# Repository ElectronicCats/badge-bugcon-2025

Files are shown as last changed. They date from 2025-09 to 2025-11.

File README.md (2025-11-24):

# Badge BugCon 2025

El Badge BugCon 2025 es un dispositivo de hardware abierto diseñado para la comunidad de hackers, desarrolladores y entusiastas de la tecnología. Cuenta con un potente procesador Linux capaz de ejecutar aplicaciones personalizadas, junto con una amplia variedad de interfaces para ampliar su funcionalidad.

## 🚀 Características Principales

### Procesador principal 
- **RV1106**: Procesador Linux de alto rendimiento
  - ARM Cortex-A7 + MCU RISC-V
  - NPU integrada (Unidad de Procesamiento Neural)
  - ISP integrado (Procesador de Señal de Imagen)
  - Soporte completo para sistemas operativos Linux

### Interfaces y Conectividad
- **GPIOs**: Múltiples pines de propósito general
- **MIPI CSI**: Interfaz para cámaras y sensores de imagen
- **UART**: Comunicación serial asíncrona
- **SPI**: Comunicación periférica de alta velocidad
- **I2C**: Bus de comunicación para sensores y pantallas
- **USB**: Puerto USB con hub integrado
- **Ethernet**: Puerto Ethernet basado en GPIO para conectividad por cable

### Periféricos Integrados
- **Neopixels**: LEDs RGB programables WS2812E
- **Batería**: Soporte para baterías 18650 con gestión de energía
- **Buck Converter**: Regulación eficiente DC-DC
- **USB-A**: Soporte para dispositivos externos

## 📦 Componentes del Proyecto

El proyecto está dividido en dos directorios principales:

### 1. Badge Principal (`Badge_Bugcon_2025/`)
Incluye el diseño principal:
- Procesador RV1106G3
- LEDs Neopixel WS2812E
- Gestión de energía y batería
- Interfaces USB

### 2. Add-on (`Add_On_Bugcon_2025/`)
Placa de expansión que incluye:
- Microcontrolador PY32F002AA15M
- Componentes adicionales para capacidades extendidas
- Diseño decorativo personalizado

## 📋 Especificaciones Técnicas

| Componente | Especificación |
|---|---|
| Procesador | RV1106G3 (ARM Cortex-A7 + RISC-V MCU + NPU + ISP) |
| Sistema Operativo | Linux |
| LEDs | WS2812E Neopixels |
| Batería | Soporte 18650 |
| Interfaces | USB, Ethernet, UART, SPI, I2C, MIPI CSI, GPIOs |

## 🔌 Interfaces del RV1106

El procesador RV1106 ofrece las siguientes interfaces:

### Comunicación
- **UART**: Comunicación serial (debug/terminal)
- **SPI**: Interfaz periférica de alta velocidad
- **I2C**: Para sensores, pantallas y otros dispositivos I2C
- **USB**: Hub USB integrado

### Red
- **Ethernet**: Conectividad por cable mediante una interfaz basada en GPIO
- **WiFi (NO INCLUIDO)**: Conectividad por USB mediante el USB HUB, drivers disponibles ya instalados en kernel.

### Multimedia e Imagen
- **MIPI CSI**: Interfaz para cámaras y sensores de imagen
- **ISP**: Procesador de señal de imagen integrado

### Control
- **GPIOs**: Pines de propósito general
- **PWM**: Canales PWM para control de LEDs y motores

# Primeros pasos 

El badge Bugcon 2025 está basado en el hardware y el SDK del Luckfox Pico Pro Max. Para información general, consulta la Wiki oficial de Luckfox. El badge incorpora el RV1106G3, un microprocesador de bajo consumo de Rockchip, basado en una CPU ARM y un co-procesador RISC-V de 32 bits optimizada para aplicaciones de codificación y decodificación de audio y video.

Nuestro primer badge con Linux embebido!

El badge es compatible con múltiples interfaces, incluyendo GPIO, UART, SPI, I²C, USB, entre otras, lo que facilita un desarrollo rápido y una depuración eficiente.

## 🔌 Conectarse al puerto serial (Debug Serial)

Para interactuar con el badge (ejecutar comandos, ver logs o depurar), debes conectarte al puerto DEBUG SERIAL mostrado en la imagen anterior.
Este puerto corresponde a la UART2 del RV1106:

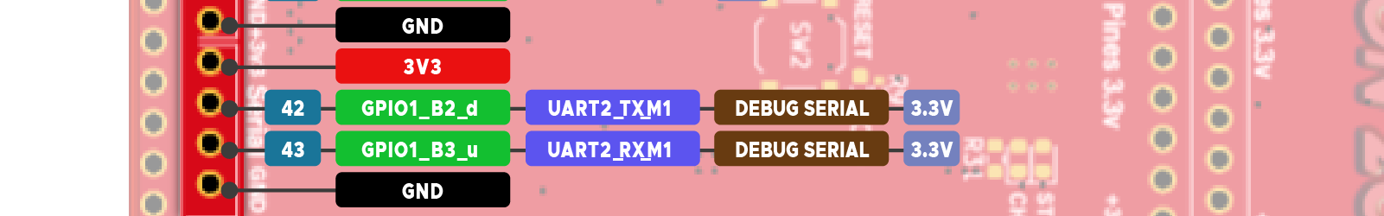
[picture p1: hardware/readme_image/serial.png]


```
TX → GPIO1_B2_d
RX → GPIO1_B3_u
```
⚠ Importante: La señal del puerto serial del badge es 3.3V TTL.

## ✔ Adaptadores USB–Serial compatibles

Puedes usar cualquier adaptador USB a UART de 3.3V, por ejemplo:

CH340 / CH341
CP2102 / CP2104
FT232RL
PL2303
CP2105

Matek F405 adapters (soportan 3.3V)

Asegúrate de:
```
TX del adaptador → RX del badge
RX del adaptador → TX del badge
GND → GND
```

## 💻 Cómo abrir la terminal serial

A continuación, cómo conectarte desde Linux, macOS y Windows.

## 🐧 Linux

Conecta el adaptador USB-serial.

Verifica qué puerto creó:
```
dmesg | grep tty
```

Normalmente aparecerá como:
```
/dev/ttyUSB0
/dev/ttyACM0
```
Conéctate con screen o minicom:

Con screen (lo más fácil)
```
screen /dev/ttyUSB0 115200
```

Para salir:
CTRL + A luego K (y confirma).

Con minicom
```
sudo minicom -b 115200 -D /dev/ttyUSB0
```

## 🍎 macOS

Conecta el adaptador USB-UART.

Ver puertos disponibles:
```
ls /dev/tty.*
```

Suelen ser:
```
/dev/tty.usbserial-*
/dev/tty.wchusbserial*
/dev/tty.SLAB_USBtoUART
```

Conéctate:

```
screen /dev/tty.usbserial-XXXX 115200
```

Para salir:
CTRL + A, luego K.

Mac también permite usar CoolTerm (GUI amigable).

## 🪟 Windows

Usa un cliente serial como:
```
PuTTY
TeraTerm
CoolTerm
RealTerm
```

Conecta el adaptador USB-UART.

Abre el Administrador de dispositivos → “Puertos (COM y LPT)”

Identifica el puerto COM, ejemplo: COM4

Abre PuTTY o TeraTerm y selecciona:
```
Port: COM4
Baudrate: 115200
Data bits: 8
Parity: None
Stop bits: 1
Flow control: None
```
Con eso verás la consola del badge.

## Pinout 

Los números de pines correspondientes a los GPIO se encuentran marcados en el diagrama de pinout. Puedes utilizarlos para configurar un pin como GPIO.
Para más información, consulta la wiki de GPIO de Luckfox.e.

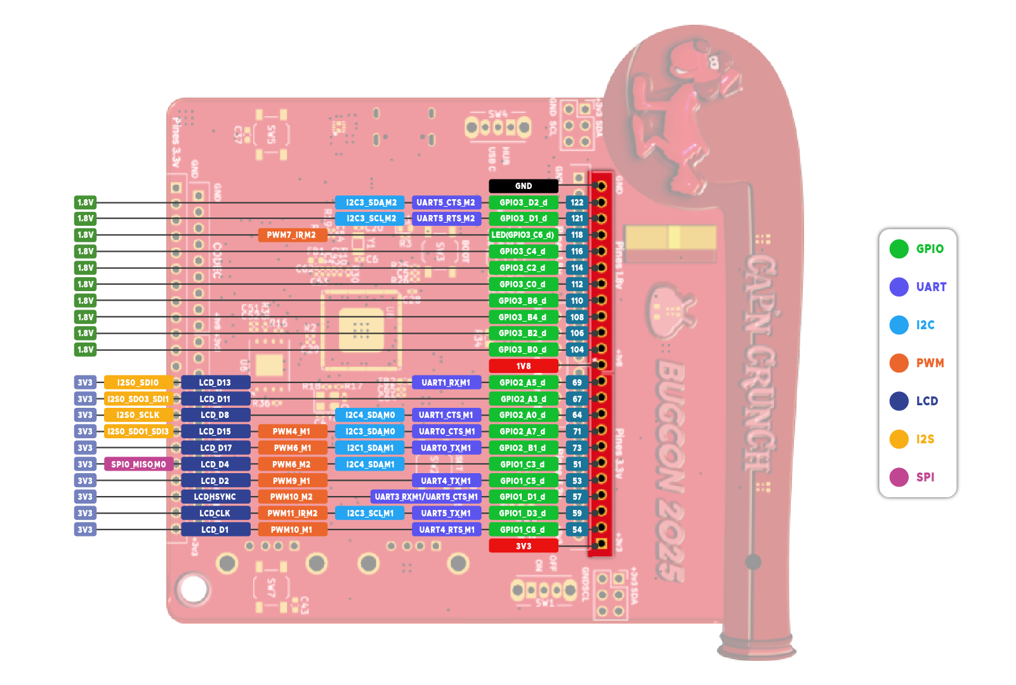
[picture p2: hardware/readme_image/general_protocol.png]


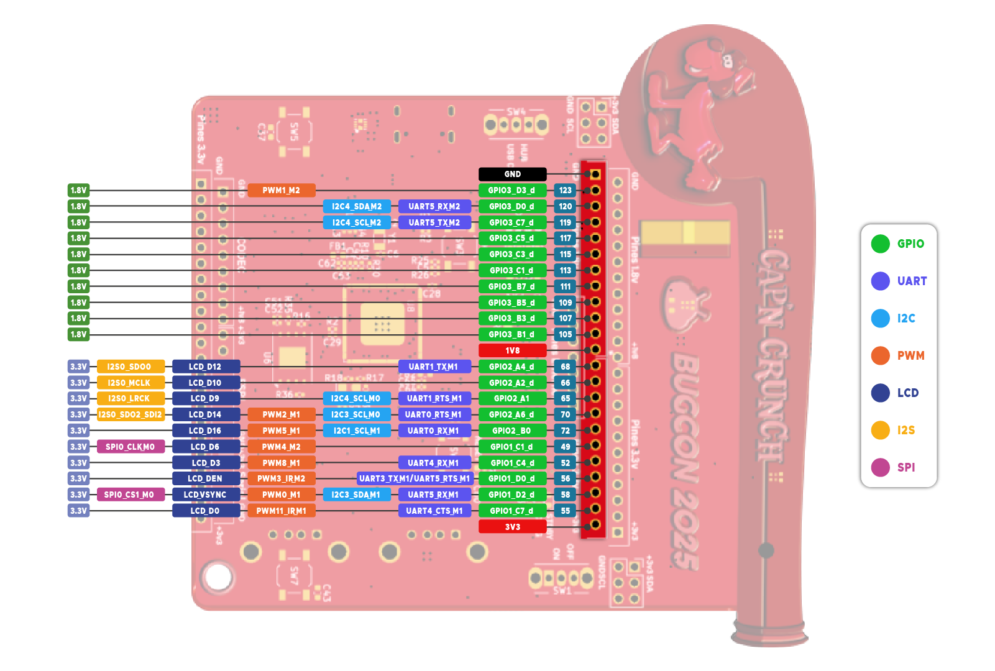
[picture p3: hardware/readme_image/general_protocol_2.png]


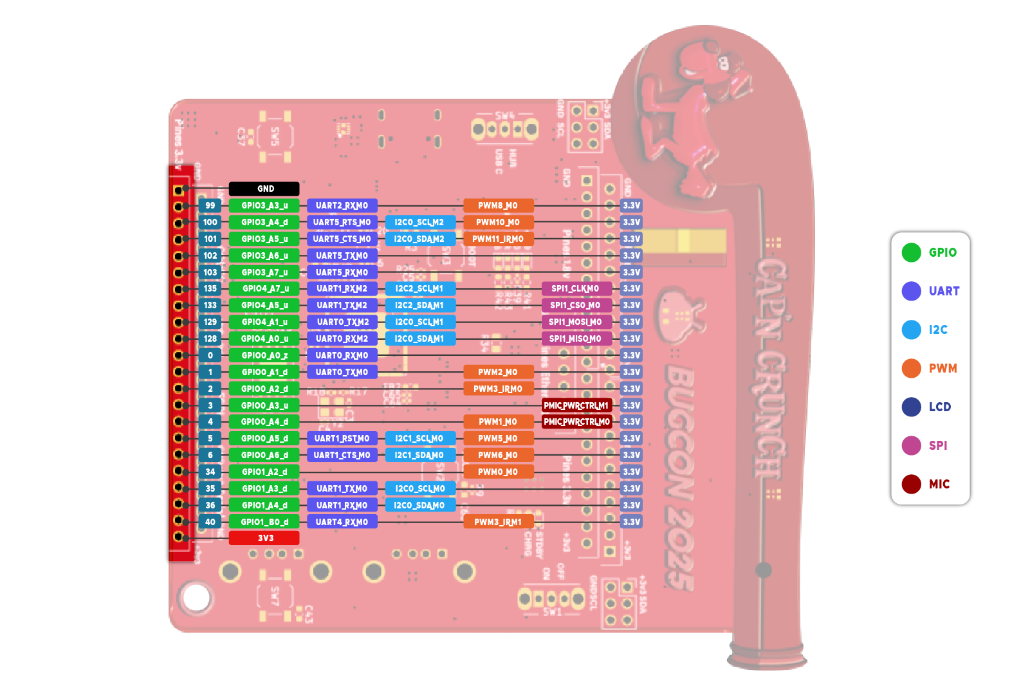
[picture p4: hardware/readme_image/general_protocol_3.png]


Los números de pines correspondientes a los GPIO se encuentran marcados en el diagrama de pinout. Puedes utilizarlos para configurar un pin como GPIO.
Para más información, consulta la wiki de GPIO de Luckfox.

- [GPIO](https://wiki.luckfox.com/Luckfox-Pico-Pro-Max/GPIO)

La tarjeta también es compatible con Ethernet de 10/100 Mbps. Ten en cuenta que es necesario agregar el transformador Ethernet (Ethernet transformer) y el common-mode choke para garantizar el funcionamiento adecuado del dispositivo.

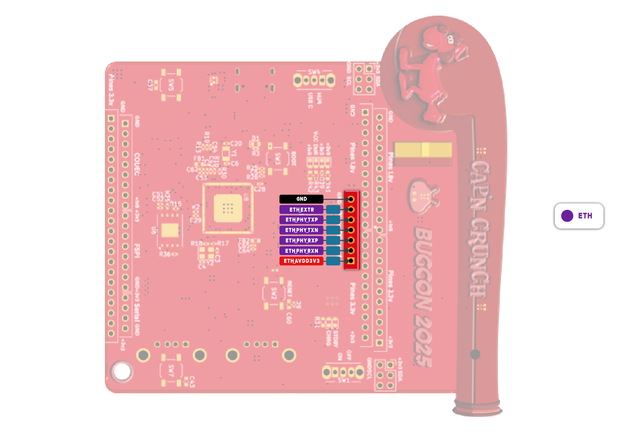
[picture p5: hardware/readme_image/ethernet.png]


Finalmente, la tarjeta permite conectar micrófonos analógicos externos a través de la entrada del códec. El CPU también puede generar señales de audio digital PCM (Pulse-Code Modulation), las cuales pueden convertirse en señales analógicas para reproducción.
Es importante destacar que la señal analógica utilizada para reproducción requiere su propio amplificador para evitar problemas relacionados con la corriente.

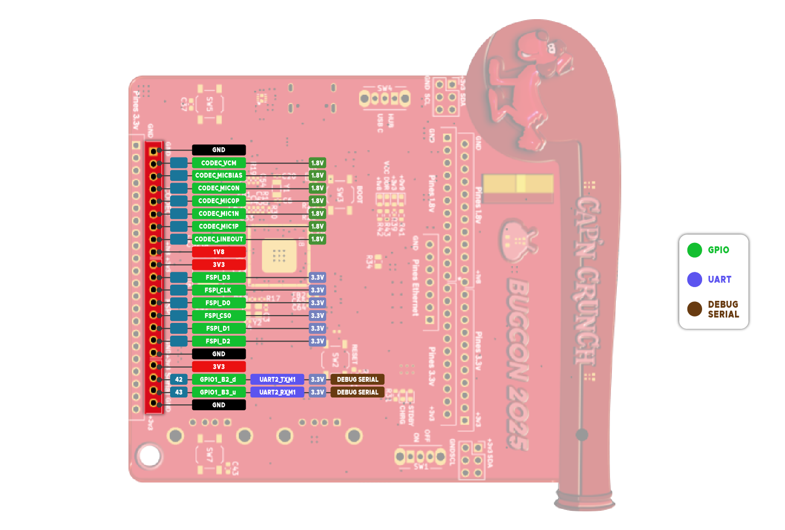
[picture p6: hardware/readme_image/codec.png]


Para más información, consulta la wiki de audio de Luckfox:

- [Audio](https://wiki.luckfox.com/Luckfox-Pico-Ultra/Audio)

IMPORTANTE: No utilices los pines FSPI. Estos están conectados directamente a la memoria flash. Cualquier alteración en sus señales puede provocar fallos en el funcionamiento del badge.

## Blink Blink!
Presiona los botones que se encuentran al frente del badge y enciende los leds!!

## Acceso:

Para acceder al dispositivo los accesos son:

*usuario:* root

*password:* 1337

## Hola Mundo

El badge ya incluye Python 3.11.6, por lo que puedes ejecutar scripts de Python directamente desde la terminal sin necesidad de configurar nada adicional.

Esta breve guía muestra cómo crear y ejecutar un simple programa “Hola Mundo”.

1. En la terminal, crea un nuevo archivo:

```
nano nombre.py
```
o
```
vi nombre.py
```

Agrega esta linea:
```
print("Hola mundo!")
```
2. Ejecuta el archivo

```
python3 nombre.py
```

you should see
```
Hola mundo !
``` 

## NEOPIXELES

Los LEDs RGB WS2812B y WS2812E-1313 pueden controlarse utilizando el módulo de Python spidev a través de la interfaz SPI del RV1106.
Es importante destacar que SPI se utiliza como un generador de trenes de pulsos a 800 kHz, lo cual es necesario para el funcionamiento correcto de los NeoPixel.

Una vez habilitados los módulos en la interfaz de configuración y grabada la tarjeta, el siguiente paso será crear un script de Python en el entorno de Buildroot dentro de la PCB.
```
nano /root/[nombre del scrip].py
```
Puede ser algo como esto:

```
#!/usr/bin/env python3
import spidev, time, threading

SPI_SPEED_HZ = 2400000
NUM_LEDS = 8

def byte_to_spi(byte):
    spi_bytes = []
    for i in range(8):
        if byte & (1 << (7-i)):
            spi_bytes.append(0b1110)  # '1'
        else:
            spi_bytes.append(0b1000)  # '0'
    return spi_bytes

def color_to_spi(r, g, b):
    data = []
    data += byte_to_spi(g)
    data += byte_to_spi(r)
    data += byte_to_spi(b)
    return data

def make_buffer(r, g, b):
    buf = []
    for _ in range(NUM_LEDS):
        buf += color_to_spi(r, g, b)
    return buf

def run_spi(bus, device, colors):
    spi = spidev.SpiDev()
    spi.open(bus, device)
    spi.max_speed_hz = SPI_SPEED_HZ

    try:
        while True:
            for (r,g,b) in colors:
                buffer = make_buffer(r,g,b)
                spi.xfer2(buffer)
                time.sleep(1)
    except KeyboardInterrupt:
        spi.xfer2(make_buffer(0,0,0))
        spi.close()

def main():
    colors = [(255,0,255), (0,255,0), (0,0,255)]  # rosa, verde, azul

    t0 = threading.Thread(target=run_spi, args=(0,0,colors))
    #t1 = threading.Thread(target=run_spi, args=(1,0,colors))

    t0.start()
    #t1.start()

    t0.join()
    #t1.join()

if __name__ == "__main__":
    main()

```
El script controla tanto los LEDs WS2812B como WS2812B-1313 a través de spi0 y spi1, alternando entre cuatro colores diferentes (azul, rojo, verde y rosa) cada segundo.
Una vez creado, ejecuta el script:
```
python3 /root/[nombre del scrip].py
```

## Device tree source 

El Device Tree es utilizado en el kernel de Linux para describir el hardware de una placa.
Está compuesto por archivos de texto con extensiones .dts (Device Tree Source) y .dtsi (Device Tree Source Include).
El archivo .dts define el hardware específico de la placa, mientras que el archivo .dtsi contiene configuraciones comunes o compartidas por múltiples .dts.

Puedes utilizar el Device Tree para habilitar, deshabilitar y/o configurar los diferentes periféricos que la tarjeta ofrece.
Los archivos del Device Tree se encuentran en el siguiente directorio del SDK:

```
 luckfox-pico SDK/sysdrv/source/kernel/arch/arm/boot/dts
```
Para más información, consulta la wiki de DTS de Luckfox:

- [DTS](https://wiki.luckfox.com/Luckfox-Pico-Ultra/Device-Tree)

## USB host mode 

Puede modificar la configuración del device tree para establecerlo como un USB HOST, lo que le permitirá ampliar múltiples interfaces mediante un USB HUB.

1. Abre la herramienta de luckfox-config en la terminal de la badge:

```
luckfox-config
```

2. Selecciona "Advanced Options":

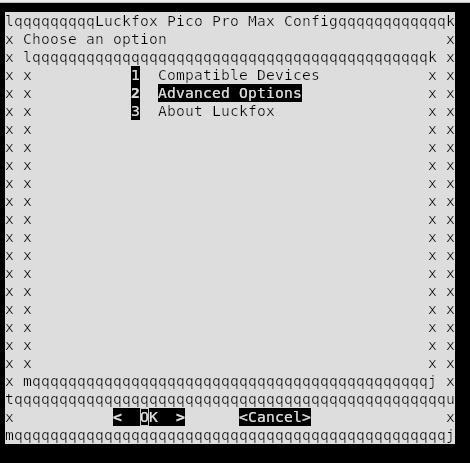
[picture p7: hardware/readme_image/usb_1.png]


3. Selecciona "USB" :

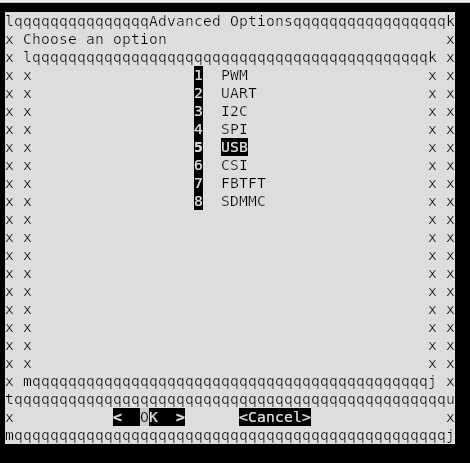
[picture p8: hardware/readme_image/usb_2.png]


4. Selecciona el modo "HOST": 

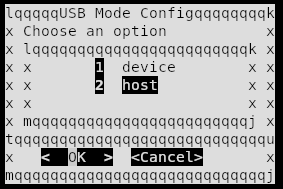
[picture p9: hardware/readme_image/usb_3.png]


5. Una vez seleccionado, usar la tecla "Esc" para salir.

# Cargar la imagen 

## Windows

Para cargar la imagen a traves de windows, es necesario descargar este zip:
```
https://drive.google.com/drive/folders/1J3xfAAmFQHFgw1gC7Ql5-bSOi6YOyE-3
```

La carpeta contiene varias imagenes necesarias para el flasheo de la placa Bugcon2025.
Una vez descargada, por favor seguir las intrucciones de la wiki de luckfox:
```
https://wiki.luckfox.com/Luckfox-Pico-Pro-Max/Flash-image
```

## Linux

1. [Descargar](https://wiki.luckfox.com/assets/files/upgrade_tool_v2.17-bfd48dcdba9fd8013872ca2abff19a8d.zip) y extraer la herramiente de actualizacion de Rockchip.
   
3. Del release, descargar y descomprimir el archivo comprimido Bugcon-Badge-2025-vX.X.tar.xz. 
    
4. Mantenga presionado el botón BOOT mientras conecta la placa a la computadora anfitriona para entrar en modo de flasheo.

5. Una vez que tengas la placa en modo BOOT, procede a flashearla. Para ello, tendras que usar el .img que se encuentra en el archivo previamente descomprimido (modifique la ruta según la ubicación real de la imagen):

```
sudo ./upgrade_tool uf  {PATH-TO-IMAGE}/Bugcon-Badge-2025-v1.0.img
```

## MAC OS

1. [Descargar](https://wiki.luckfox.com/files/RV1106/upgrade_tool_v2.44_for_mac.zip) y extraer la herramienta de actualizacion

2. Del release, descargar y descomprimir el archivo comprimido Bugcon-Badge-2025-v1.0.tar.xz. 
    
3. Mantenga presionado el botón BOOT mientras conecta la placa a la computadora anfitriona para entrar en modo de flasheo.

4. Una vez que tengas la placa en modo BOOT, procede a flashearla. Para ello, ejecute el programa para flashear el firmware (modifique la ruta según la ubicación real de la imagen) y use el .img previamente descomprimido:
```
sudo ./upgrade_tool uf  {PATH-TO-IMAGE}/Bugcon-Badge-2025-v1.0.img
```

## 📖 Documentación Adicional

- [KiCad Documentation](https://docs.kicad.org/)
- [RV1106 Datasheet](https://files.luckfox.com/wiki/Luckfox-Pico/PDF/Rockchip%20RV1106%20Datasheet%20V1.7-20231218.pdf)
- [Proyecto basado en Luckfox](https://wiki.luckfox.com/Luckfox-Pico-RV1106)
- [SDK basado en Badge](https://github.com/ElectronicCats/luckfox-pico/tree/bugcon2025)

## 🤝 Contribuciones

Este es un proyecto de hardware abierto. Las contribuciones son bienvenidas:

1. Haz un fork del repositorio.
2. Crea una nueva rama para tu feature (`git checkout -b feature/AmazingFeature`)
3. Haz commit de tus cambios (`git commit -m 'Add some AmazingFeature'`)
4. Haz push a tu rama (`git push origin feature/AmazingFeature`)
5. Abre un Pull Request

## 📝 Licencia

Este proyecto es de hardware abierto. Consulta los archivos de licencia para más detalles.

## 🏢 Electronic Cats

Desarollado con ❤️ por [Electronic Cats](https://www.electroniccats.com/)

<a href="https://github.com/sponsors/ElectronicCats">

</a>

Electronic Cats invierte tiempo y recursos en proporcionar este diseño de hardware abierto.
Por favor, apoya a Electronic Cats y al hardware abierto comprando productos de Electronic Cats.

## 📞 Contacto y soporte 

- **Website**: [https://www.electroniccats.com/](https://www.electroniccats.com/)
- **GitHub**: [ElectronicCats](https://github.com/ElectronicCats)
- **Issues**: Usa la sección de Issues en GitHub para reportar problemas o sugerir mejoras

## 🙏 Agradecimientos

Gracias a toda la comunidad de hardware abierto y a todas las personas que hacen posibles proyectos como este.
---

Nota: Este badge está diseñado para BugCon 2025. Para más información sobre el evento, visita la página oficial de BugCon.

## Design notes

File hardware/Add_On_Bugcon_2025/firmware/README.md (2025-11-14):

# PY32F0 Template Project for Windows

More about hardware and development kit:  [TDLOGY Dev Resource](https://github.com/TDLOGY/PY32F002A-Dev-Resource)

Fork from: https://github.com/IOsetting/py32f0-template with modify makefile to support Windows

* Puya PY32F0 seriees template project for GNU Arm Embedded Toolchain
* Supported programmers: J-Link
* Supported IDE: VSCode

# Puya PY32F0 Family

* PY32F002A
  * PY32F002Ax5(20KB Flash/3KB RAM)

**Note**

There is high probability that PY32F002A, PY32F003 and PY32F030 share the same core, you can treat them all as PY32F030 in coding and programming.

# File Structure

```
├── Build                       # Build results
├── Docs                        # Datesheets and User Manuals
├── Examples
│   ├── FreeRTOS                # FreeRTOS examples
│   ├── HAL                     # HAL library examples
│   └── LL                      # LL(Low Layer) library examples
├── Libraries
│   ├── BSP                     # SysTick delay and printf for debug
│   ├── BSP_LL                  # SysTick delay and printf for debug
│   ├── CMSIS
│   ├── FreeRTOS                # FreeRTOS library
│   ├── LDScripts               # LD files
│   ├── PY32F0xx_HAL_Driver     # MCU peripheral driver
│   └── PY32F0xx_LL_Driver      # MCU low layer peripheral driver
├── Makefile                    # Make config
├── Misc
│   ├── Flash
│   │   ├── JLinkDevices        # JLink flash loaders
│   │   └── Sources             # Flash algorithm source code
│   ├── Puya.PY32F0xx_DFP.x.pack # DFP pack file for PyOCD
│   └── SVD                     # SVD files
├── README.md
├── rules.mk                    # Pre-defined rules include in Makefile 
└── User                        # User application code
```

# Requirements

* PY32F0 EVB or boards of PY32F002/003/030 series: https://linhkienthuduc.com//product/search?search=PY32
* Programmer
  * J-Link: J-Link OB programmer: https://linhkienthuduc.com/jlink-ob-072-mach-nap-cho-arm-cortex-m
* SEGGER J-Link Software and Documentation pack [https://www.segger.com/downloads/jlink/](https://www.segger.com/downloads/jlink/)
* GNU Arm Embedded Toolchain
* Make 

# Building

## 1a. Install GNU Arm Embedded Toolchain

Download the toolchain from [Arm GNU Toolchain Downloads](https://developer.arm.com/downloads/-/arm-gnu-toolchain-downloads) according to your pc architecture, extract the files and install:

**Note: Don't download Cortex-M PACBTI Version**

## 1b. Install Make
Download make 3.81 Binaries from: https://gnuwin32.sourceforge.net/packages/make.htm

**Note: Add Make path to PATH: C:\Program Files (x86)\GnuWin32\bin**

## 2. : Install SEGGER J-Link (Must)

Download and install JLink from [J-Link / J-Trace Downloads](https://www.segger.com/downloads/jlink/).

Must: Copy [Project directory]/Misc/Flash/JLinkDevices to C:\Users\[Users]\AppData\Roaming\SEGGER\JLinkDevices\

Read more: [https://wiki.segger.com/J-Link_Device_Support_Kit](https://wiki.segger.com/J-Link_Device_Support_Kit)

## 3. Clone This Repository

Clone this repository to local workspace
```
git clone https://github.com/TDLOGY/py32f0-template-project
```

Or download directly from link: https://github.com/TDLOGY/py32f0-template-project

## 4. Edit Makefile

Change the settings in Makefile
* **USE_LL_LIB** Puya provides two sets of library, HAL and LL, set `USE_LL_LIB ?= y` to use LL instead of HAL.
* **ENABLE_PRINTF_FLOAT** set it to `y` to `-u _printf_float` to link options. This will increase the binary size.
* **USE_FREERTOS** Set `USE_FREERTOS ?= y` will include FreeRTOS in compilation
* **USE_DSP** Include CMSIS DSP or not
* **FLASH_PROGRM**
  * If you use J-Link, `FLASH_PROGRM` jlink
  * ST-LINK is not supported yet.
* **ARM_TOOCHAIN** Make sure it points to the correct path of arm-none-eabi-gcc

```makefile
##### Project #####

PROJECT           ?= app
# The path for generated files
BUILD_DIR         = Build

##### Options #####

# Use LL library instead of HAL, y:yes, n:no
USE_LL_LIB        ?= n
# Enable printf float %f support, y:yes, n:no
ENABLE_PRINTF_FLOAT ?= n
# Build with FreeRTOS, y:yes, n:no
USE_FREERTOS      ?= n
# Build with CMSIS DSP functions, y:yes, n:no
USE_DSP           ?= n
# Programmer, jlink or pyocd
FLASH_PROGRM      ?= pyocd

ifeq ($(detected_OS),WIN)     # is Windows_NT on XP, 2000, 7, Vista, 10...
ARM_TOOCHAIN	?= C:/Program Files (x86)/Arm GNU Toolchain arm-none-eabi/12.2 rel1/bin
JLINKEXE		?= C:/Program Files/SEGGER/JLink/JLink
else
ARM_TOOCHAIN	?= /opt/gcc-arm/arm-gnu-toolchain-12.2.rel1-x86_64-arm-none-eabi/bin
JLINKEXE		?= /opt/SEGGER/JLink/JLinkExe
endif

# JLink device type, options:
#   PY32F002AX5, PY32F002X5, 
#   PY32F003X4, PY32F003X6, PY32F003X8, 
#   PY32F030X4, PY32F030X6, PY32F030X7, PY32F030X8
JLINK_DEVICE      ?= PY32F030X6
# path to PyOCD, 
PYOCD_EXE         ?= pyocd
# PyOCD device type, options: 
#     py32f002ax5, py32f002x5, 
#   py32f003x4,  py32f003x6, py32f003x8, 
#   py32f030x3,  py32f030x4, py32f030x6, py32f030x7, py32f030x8
#   py32f072xb
PYOCD_DEVICE      ?= py32f030x8

##### Paths ############

# Link descript file: py32f002x5.ld, py32f003x6.ld, py32f003x8.ld, py32f030x6.ld, py32f030x8.ld
LDSCRIPT          = Libraries/LDScripts/py32f002x5.ld
# Library build flags: 
#   PY32F002x5, PY32F002Ax5, 
#   PY32F003x4, PY32F003x6, PY32F003x8, 
#   PY32F030x3, PY32F030x4, PY32F030x6, PY32F030x7, PY32F030x8, 
#   PY32F072xB
LIB_FLAGS         = PY32F030x6
```

## 5. Compiling And Flashing

```bash
# clean source code
make clean
# build
make
# or make with verbose output, Linux only
V=1 make
# flash
make flash
# erase
make erase
```
# Hardware connection

Hardware connection digram

Signal Name | Kit | Jlink
--- | --- | --- | 
VCC | 5V | VCC 3.3V
GND | GND | GND
SWCLK | SCK | SWCLK
SWDIO | SWD | SWDIO
RESET | nRST | RST
MCU_UART_TX | PA2 | RXD
MCU_UART_RX | PA1 | TXD

# Debugging In VSCode

Install Cortex Debug extension, add a new configuration in launch.json, e.g.
```
{
    // Use IntelliSense to learn about possible attributes.
    // Hover to view descriptions of existing attributes.
    // For more information, visit: https://go.microsoft.com/fwlink/?linkid=830387
    "version": "0.2.0",
    "configurations": [
        {
            "cwd": "${workspaceRoot}",
            "executable": "${workspaceFolder}/Build/app.elf",
            "name": "Debug Microcontroller",
            "request": "launch",
            "type": "cortex-debug",
            "servertype": "jlink",
            "serverpath": "C:/Program Files/SEGGER/JLink/JLinkGDBServerCL.exe",
            "armToolchainPath": "C:/Program Files (x86)/Arm GNU Toolchain arm-none-eabi/12.2 rel1/bin",
            "device": "PY32F030X8",
            "interface": "swd",
            "serialNumber": "", // add J-Link serial number if having multiple attached the same time.
            "svdFile": "${workspaceFolder}/Misc/SVD/py32f030xx.svd",

            "showDevDebugOutput": "vscode", // parsed, raw, vscode:vscode log and raw
            "runToEntryPoint": "main", // "main" or other function name. runToMain is deprecated
            "preLaunchTask": "build",  // Set this to run a task from tasks.json before starting a debug session
        }
    ]
}
```

task.json
```
{
    // See https://go.microsoft.com/fwlink/?LinkId=733558
    // for the documentation about the tasks.json format
    "version": "2.0.0",
    "tasks": [
        {
            "label": "build",
            "type": "shell",
            "command": "make -j4"
        }
    ]
}
```

# Try Other Examples

More examples can be found in *Examples* folder, copy and replace the files under *User* folder to try different examples.

# Links

* Puya Product Page(Datasheet & SDK download): https://www.puyasemi.com/cpzx3/info_267_aid_242_kid_235.html

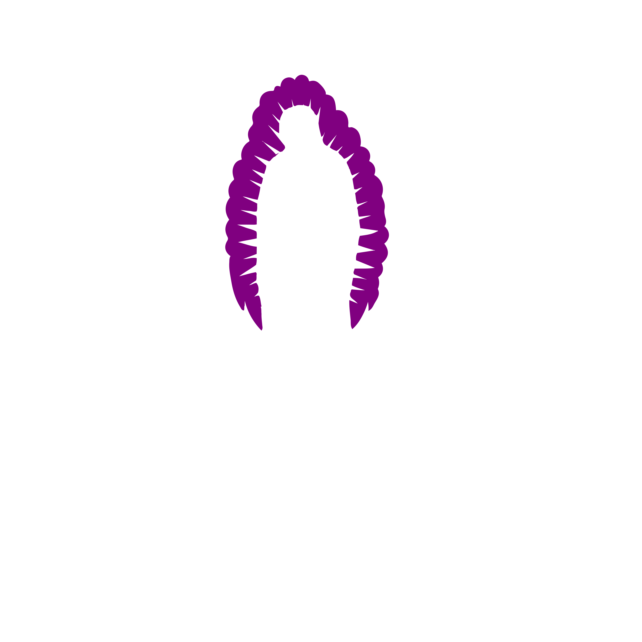
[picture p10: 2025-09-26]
hardware/Add_On_Bugcon_2025/.svg2shenzhen-cache/images/F.Cu_g587.png

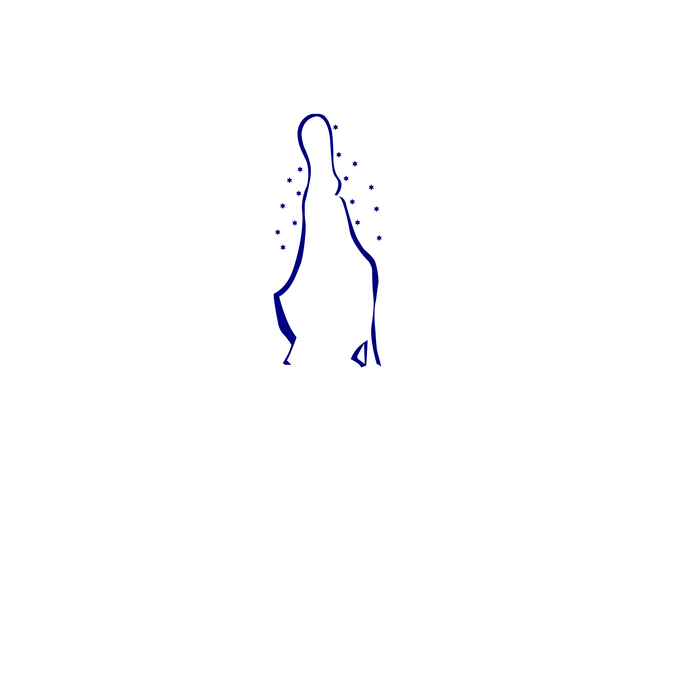
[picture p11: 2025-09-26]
hardware/Add_On_Bugcon_2025/.svg2shenzhen-cache/images/F.Mask_g589.png

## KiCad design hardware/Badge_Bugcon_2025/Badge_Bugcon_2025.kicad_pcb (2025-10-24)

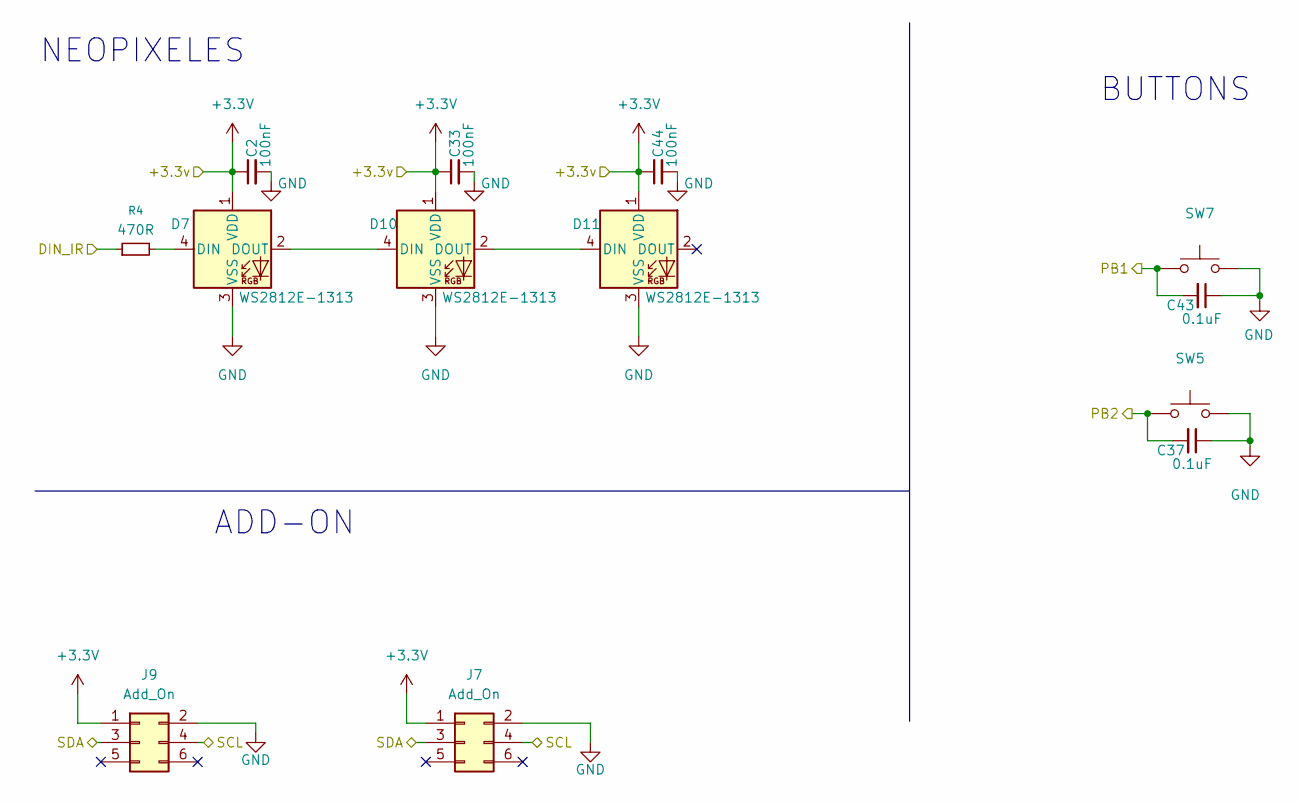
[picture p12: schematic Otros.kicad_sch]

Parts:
C2, C33, C44: 100nF; C_0402_1005Metric; LCSC# C77020
C37, C43: 0.1uF; C_0603_1608Metric; LCSC# C478888
D7, D10, D11: WS2812E-1313; LCSC# C5446700
J7, J9: Add_On; PinSocket_2x03_P2.54mm_Vertical; LCSC# C5116527
R4: 470R; R_0603_1608Metric; LCSC# C23179
SW5, SW7: SW_SPST_TL3342; LCSC# C318889

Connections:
+3.3V: C2.1, C33.1, C44.1, D7.1 (VDD), D10.1 (VDD), D11.1 (VDD), J7.1, J9.1; also elsewhere on the board
/MCU/DIN_IR: R4.1; also elsewhere on the board
/MCU/PB1: C43.2, SW7.2; also elsewhere on the board
/MCU/PB2: C37.2, SW5.2; also elsewhere on the board
/MCU/SCL: J7.4, J9.4; also elsewhere on the board
/MCU/SDA: J7.3, J9.3; also elsewhere on the board
GND: C2.2, C33.2, C37.1, C43.1, C44.2, D7.3 (VSS), D10.3 (VSS), D11.3 (VSS), J7.2, J9.2, SW5.1, SW7.1; also elsewhere on the board
unnamed: D7.4 (DIN), R4.2
unnamed: D7.2 (DOUT), D10.4 (DIN)
unnamed: D10.2 (DOUT), D11.4 (DIN)

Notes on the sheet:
BUTTONS
NEOPIXELES
ADD-ON

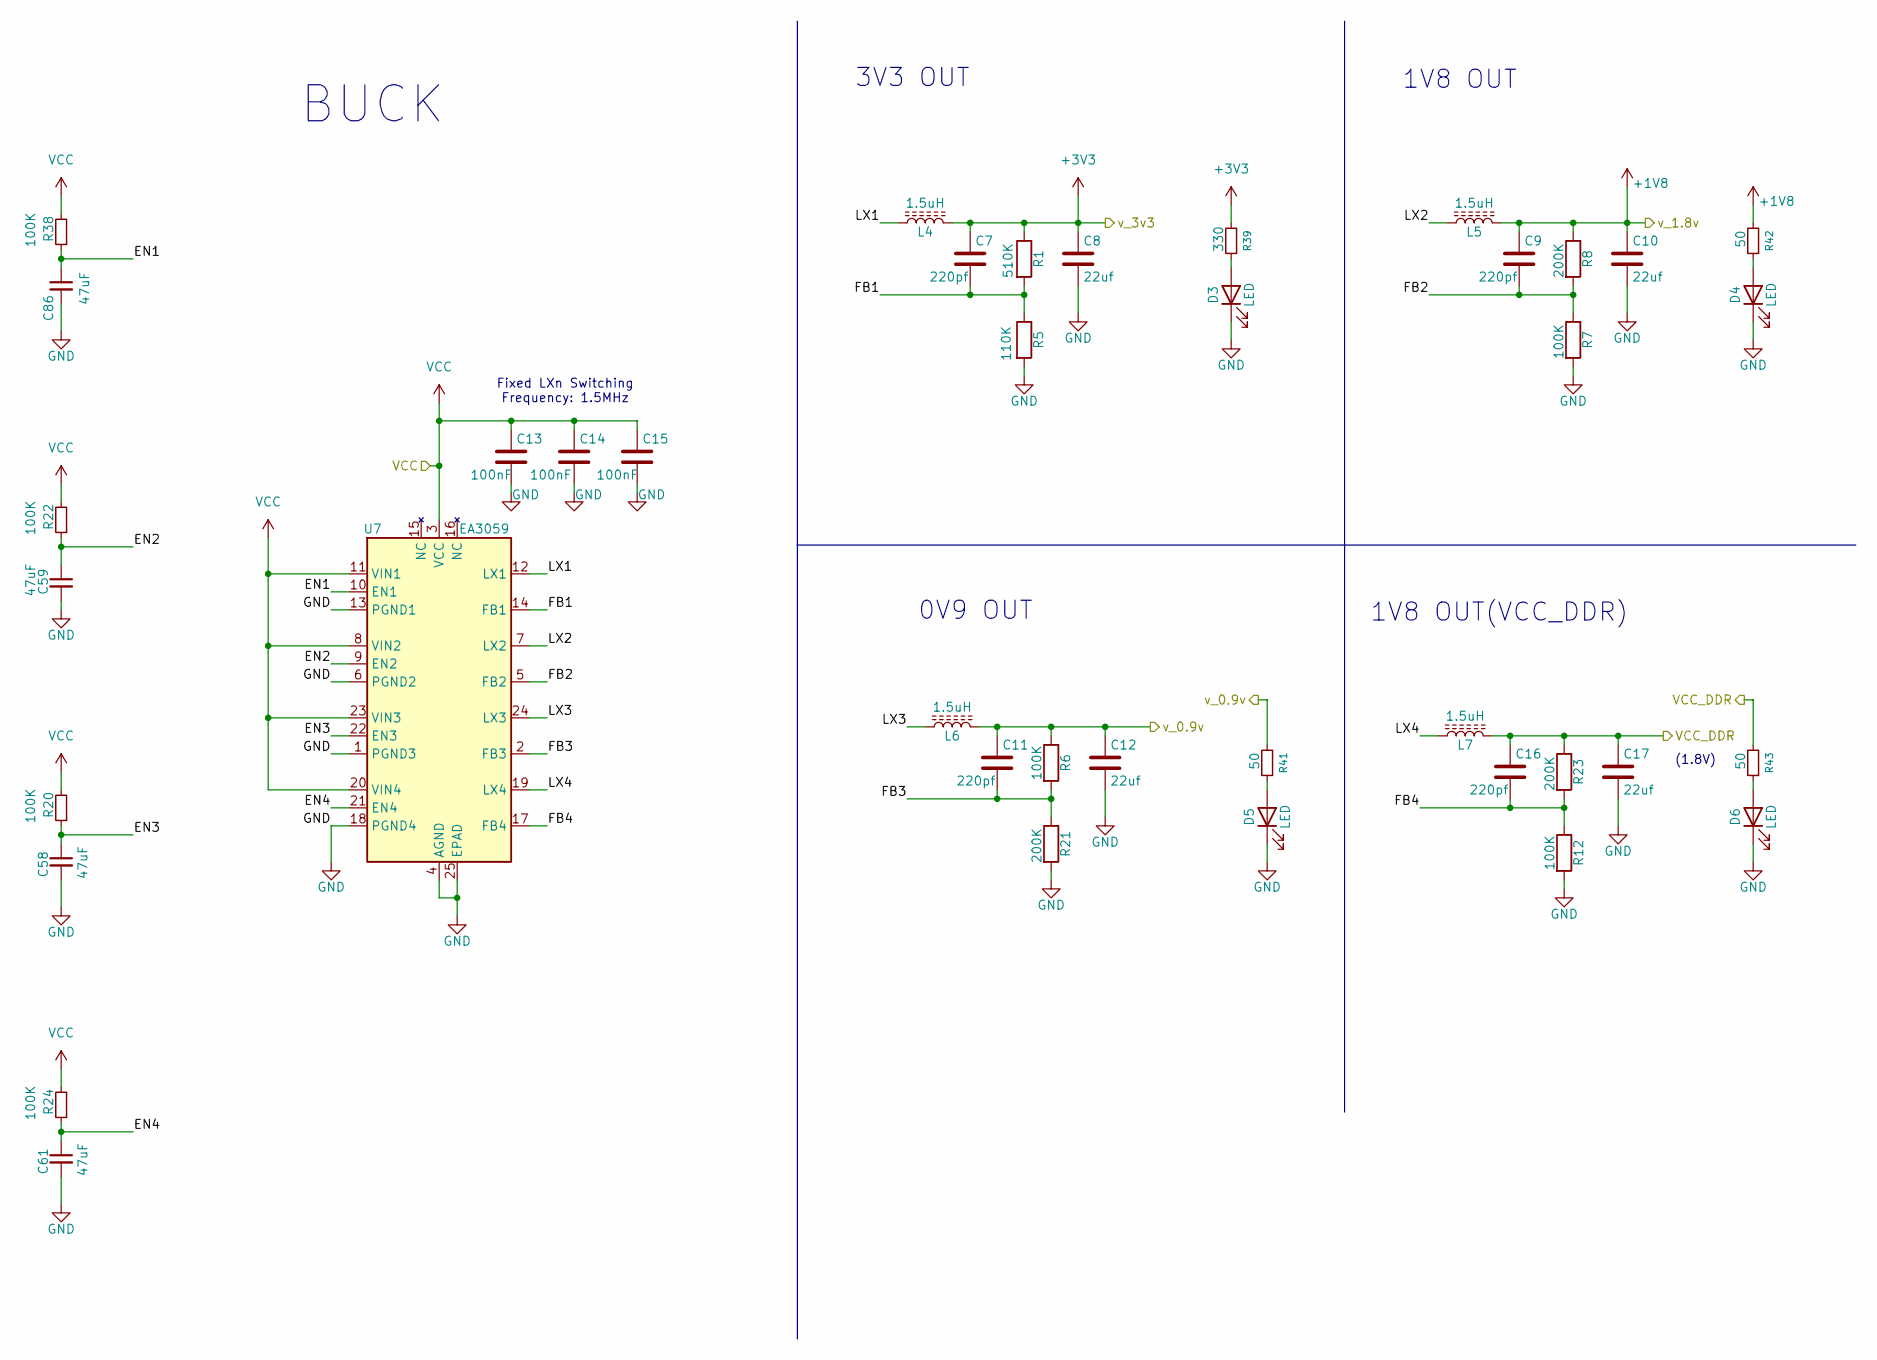
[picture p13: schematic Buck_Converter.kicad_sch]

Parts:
C7, C9, C11, C16: 220pf; C_0402_1005Metric; LCSC# C107001
C8, C10, C12, C17: 22uf; C_0402_1005Metric; LCSC# C415703
C13, C14, C15: 100nF; C_0402_1005Metric; LCSC# C77020
C58, C59, C61, C86: 47uF; C_0603_1608Metric; LCSC# C140782
D3, D4, D5, D6: LED; LED_0603_1608Metric; LCSC# C375573
L4, L5, L6, L7: 1.5uH; L_1008_2520Metric; LCSC# C7427193
R1: 510K; R_0402_1005Metric; LCSC# C365024
R5: 110K; R_0402_1005Metric; LCSC# C2909311
R6, R7, R12, R20, R22, R24, R38: 100K; R_0402_1005Metric; LCSC# C844674
R8, R21, R23: 200K; R_0402_1005Metric; LCSC# C364966
R39: 330; R_0402_1005Metric; LCSC# C105875
R41, R42, R43: 50; R_0603_1608Metric; LCSC# C2907181
U7: EA3059; VQFN-24-1EP_4x4mm_P0.5mm_EP2.5x2.5mm; LCSC# C111586

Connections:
+1V8: C9.1, C10.1, L5.2, R8.1, R42.2; also elsewhere on the board
+3V3: C7.1, C8.1, L4.2, R1.1, R39.2; also elsewhere on the board
/Buck_Converter/EN1: C86.1, R38.1, U7.10 (EN1)
/Buck_Converter/EN2: C59.1, R22.1, U7.9 (EN2)
/Buck_Converter/EN3: C58.1, R20.1, U7.22 (EN3)
/Buck_Converter/EN4: C61.1, R24.1, U7.21 (EN4)
/Buck_Converter/FB1: C7.2, R1.2, R5.1, U7.14 (FB1)
/Buck_Converter/FB2: C9.2, R7.1, R8.2, U7.5 (FB2)
/Buck_Converter/FB3: C11.2, R6.2, R21.1, U7.2 (FB3)
/Buck_Converter/FB4: C16.2, R12.1, R23.2, U7.17 (FB4)
/Buck_Converter/LX1: L4.1, U7.12 (LX1)
/Buck_Converter/LX2: L5.1, U7.7 (LX2)
/Buck_Converter/LX3: L6.1, U7.24 (LX3)
/Buck_Converter/LX4: L7.1, U7.19 (LX4)
/Buck_Converter/VCC_DDR: C16.1, C17.1, L7.2, R23.1, R43.2; also elsewhere on the board
/Buck_Converter/v_0.9v: C11.1, C12.1, L6.2, R6.1, R41.2; also elsewhere on the board
GND: C8.2, C10.2, C12.2, C13.2, C14.2, C15.2, C17.2, C58.2, C59.2, C61.2, C86.2, D3.1 (K), D4.1 (K), D5.1 (K), D6.1 (K), R5.2, R7.2, R12.2, R21.2, U7.1 (PGND3), U7.4 (AGND), U7.6 (PGND2), U7.13 (PGND1), U7.18 (PGND4), U7.25 (EPAD); also elsewhere on the board
unnamed: D3.2 (A), R39.1
unnamed: D4.2 (A), R42.1
unnamed: D5.2 (A), R41.1
unnamed: D6.2 (A), R43.1
VCC: C13.1, C14.1, C15.1, R20.2, R22.2, R24.2, R38.2, U7.3 (VCC), U7.8 (VIN2), U7.11 (VIN1), U7.20 (VIN4), U7.23 (VIN3); also elsewhere on the board

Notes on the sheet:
BUCK
0V9 OUT
Fixed LXn Switching Frequency: 1.5MHz
(1.8V)
1V8 OUT(VCC_DDR)
3V3 OUT
1V8 OUT

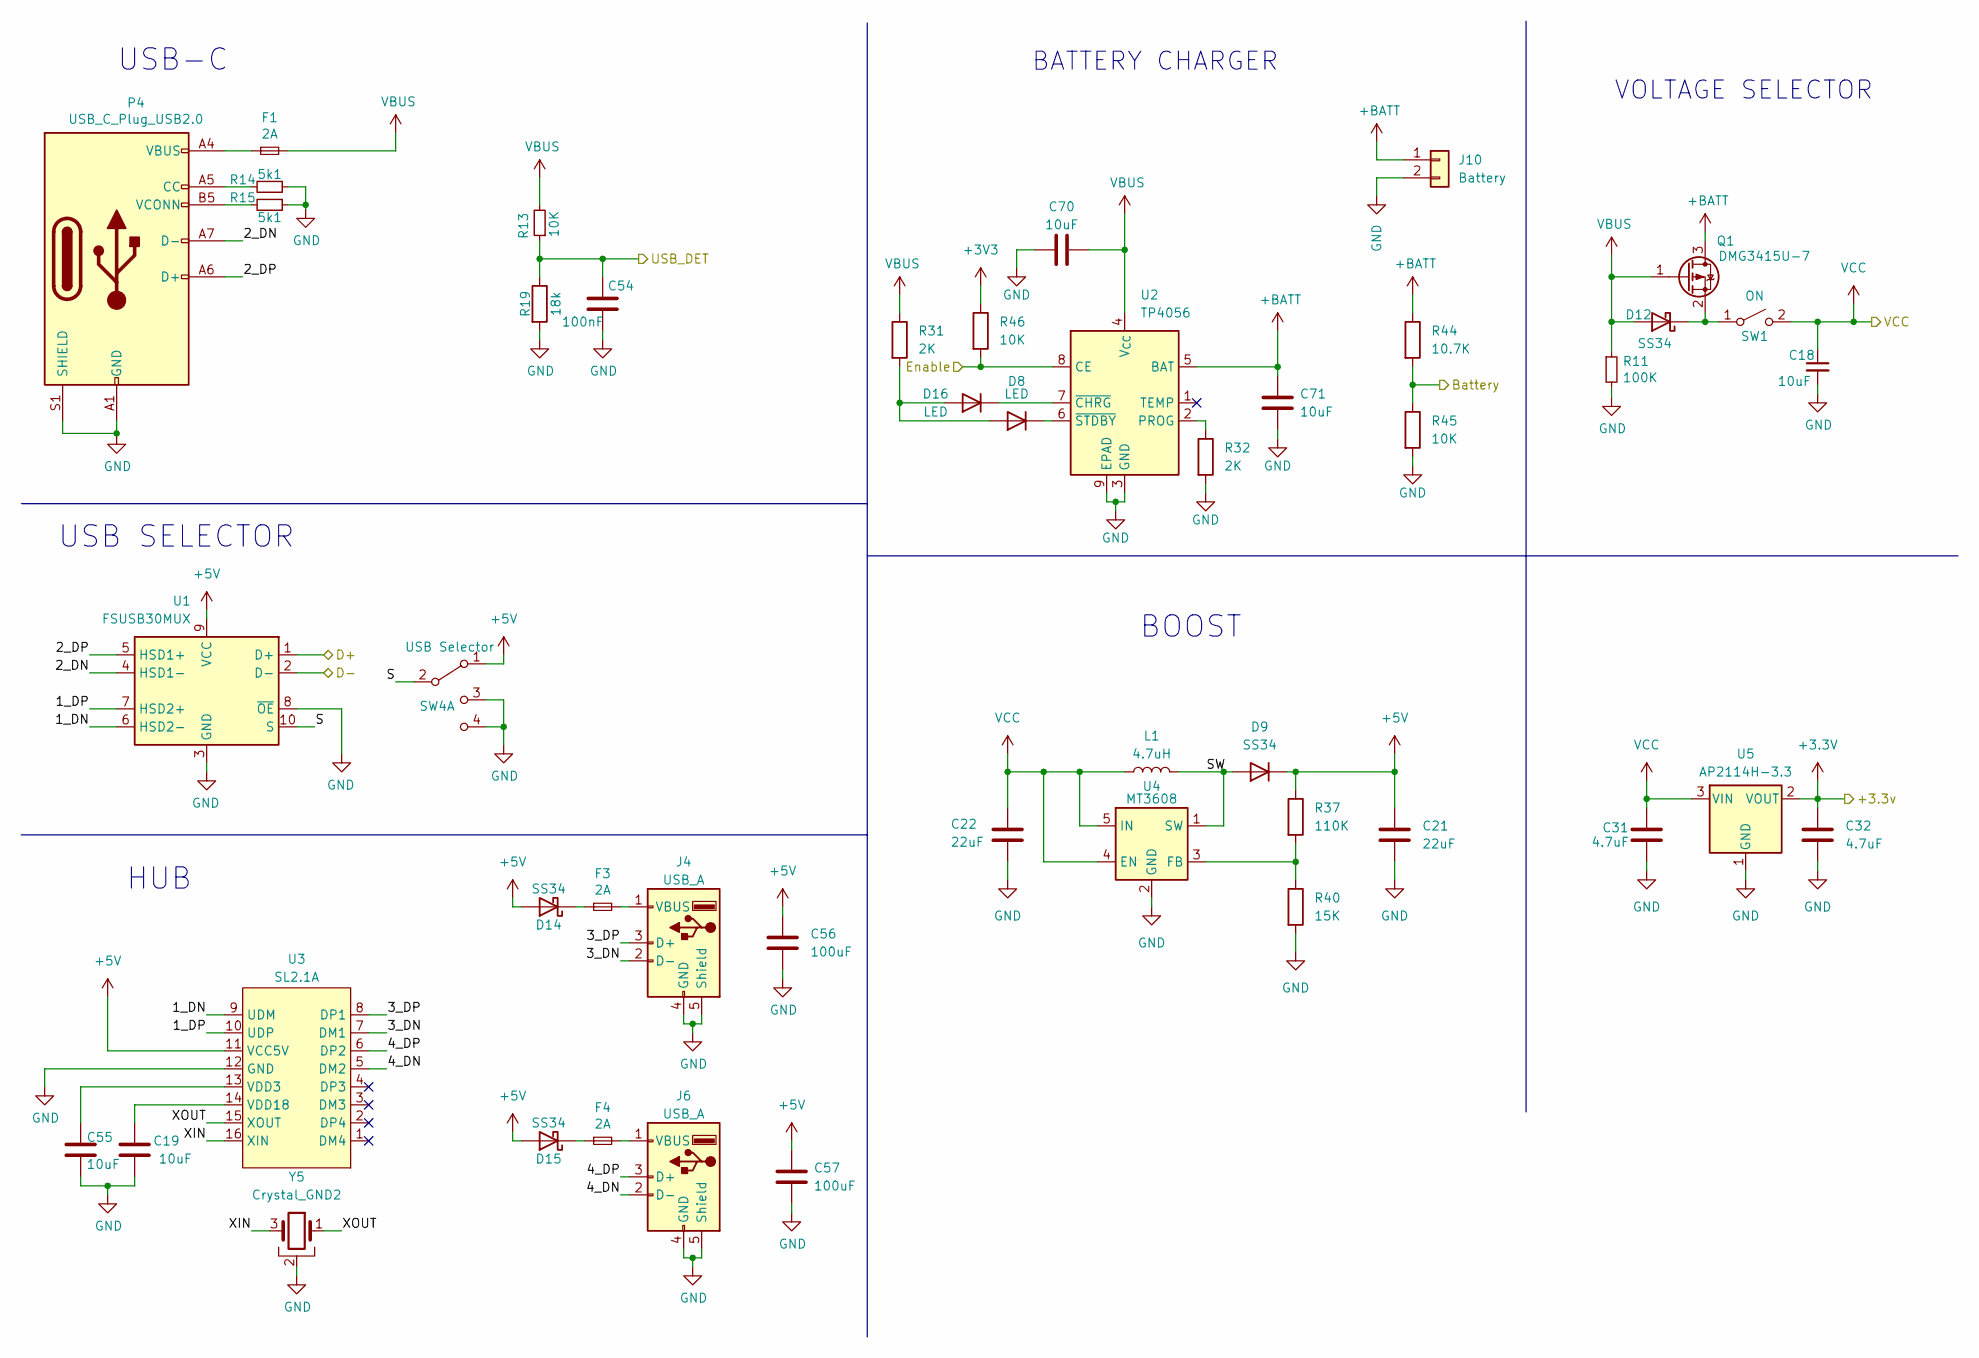
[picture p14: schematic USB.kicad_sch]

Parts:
C18: 10uF; C_0402_1005Metric; LCSC# C7472949
C19, C55, C70, C71: 10uF; C_0603_1608Metric; LCSC# C96446
C21, C22: 22uF; C_0402_1005Metric; LCSC# C415703
C31, C32: 4.7uF; C_0402_1005Metric; LCSC# C368809
C54: 100nF; C_0402_1005Metric; LCSC# C77020
C56, C57: 100uF; C_0805_2012Metric; LCSC# C141660
D8, D16: LED; LED_0603_1608Metric; LCSC# C375573
D9, D12, D14, D15: SS34; D_SMA; LCSC# C908680
F1, F3, F4: 2A; Fuse_0603_1608Metric; LCSC# C41380229
J4, J6: USB_A; USB_A_Connfly_DS1095; LCSC# C2345
J10: Battery; BatteryHolder_Keystone_1042_1x18650; LCSC# C2988620
L1: 4.7uH; LQH5BPN; LCSC# C520334
P4: USB_C_Plug_USB2.0; C393939; LCSC# C2760486
Q1: DMG3415U-7; SOT-23; LCSC# C96616
R11: 100K; R_0603_1608Metric; LCSC# C15458
R13, R45, R46: 10K; R_0402_1005Metric; LCSC# C2759535
R14, R15: 5k1; R_0603_1608Metric; LCSC# C2907044
R19: 18k; R_0402_1005Metric; LCSC# C323741
R31, R32: 2K; R_0603_1608Metric; LCSC# C2907022
R37: 110K; R_0603_1608Metric; LCSC# C326736
R40: 15K; R_0603_1608Metric; LCSC# C2989599
R44: 10.7K; R_0402_1005Metric; LCSC# C2998172
SW1: ON; SW_Slide_SPDT_Angled_CK_OS102011MA1Q; LCSC# C393937
SW4: USB Selector; SW_Slide_SPDT_Angled_CK_OS102011MA1Q; LCSC# C393937
U1: FSUSB30MUX; IC_FSUSB42UMX; LCSC# C42370490
U2: TP4056; SOIC-8-1EP_3.9x4.9mm_P1.27mm_EP2.41x3.3mm_ThermalVias; LCSC# C725790
U3: SL2.1A; SOP-16_3.9x9.9mm_P1.27mm; LCSC# C192893
U4: MT3608; SOT-23-6; LCSC# C2932326
U5: AP2114H-3.3; SOT-223-3_TabPin2; LCSC# C150716
Y5: Crystal_GND2; Crystal_SMD_3225-4Pin_3.2x2.5mm; LCSC# C133334

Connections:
+3.3V: C32.1, U5.2 (VOUT); also elsewhere on the board
+3V3: R46.1; also elsewhere on the board
+5V: C21.1, C56.1, C57.1, D9.1 (K), D14.2 (A), D15.2 (A), R37.1, SW4.1 (A), U1.9 (VCC), U3.11 (VCC5V)
+BATT: C71.1, J10.1, Q1.3 (D), R44.1, U2.5 (BAT)
/MCU/Battery: R44.2, R45.1; also elsewhere on the board
/MCU/D+: U1.1 (D+); also elsewhere on the board
/MCU/D-: U1.2 (D-); also elsewhere on the board
/MCU/Enable: R46.2, U2.8 (CE); also elsewhere on the board
/MCU/USB_DET: C54.1, R13.1, R19.1; also elsewhere on the board
/USB/1_DN: U1.6 (HSD2-), U3.9 (UDM)
/USB/1_DP: U1.7 (HSD2+), U3.10 (UDP)
/USB/2_DN: P4.A7 (D-), U1.4 (HSD1-)
/USB/2_DP: P4.A6 (D+), U1.5 (HSD1+)
/USB/3_DN: J4.2 (D-), U3.7 (DM1)
/USB/3_DP: J4.3 (D+), U3.8 (DP1)
/USB/4_DN: J6.2 (D-), U3.5 (DM2)
/USB/4_DP: J6.3 (D+), U3.6 (DP2)
/USB/S: SW4.2 (B), U1.10 (S)
/USB/SW: D9.2 (A), L1.2, U4.1 (SW)
/USB/XIN: U3.16 (XIN), Y5.3
/USB/XOUT: U3.15 (XOUT), Y5.1
GND: C18.2, C19.1, C21.2, C22.2, C31.2, C32.2, C54.2, C55.2, C56.2, C57.2, C70.1, C71.2, J4.4 (GND), J4.5 (Shield), J6.4 (GND), J6.5 (Shield), J10.2, P4.A1 (GND), P4.A12 (GND), P4.B1 (GND), P4.B12 (GND), P4.S1 (SHIELD), R11.2, R14.1, R15.1, R19.2, R32.2, R40.2, R45.2, SW4.3 (C), SW4.4 (C), U1.3 (GND), U1.8 (~OE), U2.3 (GND), U2.9 (EPAD), U3.12 (GND), U4.2 (GND), U5.1 (GND), Y5.2, Y5.4; also elsewhere on the board
unnamed: D8.1 (K), U2.6 (~STDBY)
unnamed: D12.1 (K), Q1.2 (S), SW1.1 (A)
unnamed: D14.1 (K), F3.1
unnamed: D15.1 (K), F4.1
unnamed: D8.2 (A), D16.2 (A), R31.2
unnamed: D16.1 (K), U2.7 (~CHRG)
unnamed: F1.1, P4.A4 (VBUS), P4.A9 (VBUS), P4.B4 (VBUS), P4.B9 (VBUS)
unnamed: F3.2, J4.1 (VBUS)
unnamed: F4.2, J6.1 (VBUS)
unnamed: P4.A5 (CC), R14.2
unnamed: P4.B5 (VCONN), R15.2
unnamed: R32.1, U2.2 (PROG)
unnamed: C55.1, U3.13 (VDD3)
unnamed: C19.2, U3.14 (VDD18)
unnamed: R37.2, R40.1, U4.3 (FB)
VBUS: C70.2, D12.2 (A), F1.2, Q1.1 (G), R11.1, R13.2, R31.1, U2.4 (V_{CC})
VCC: C18.1, C22.1, C31.1, L1.1, SW1.2 (B), U4.4 (EN), U4.5 (IN), U5.3 (VIN); also elsewhere on the board

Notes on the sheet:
VOLTAGE SELECTOR
BOOST
USB-C
USB SELECTOR
BATTERY CHARGER
HUB

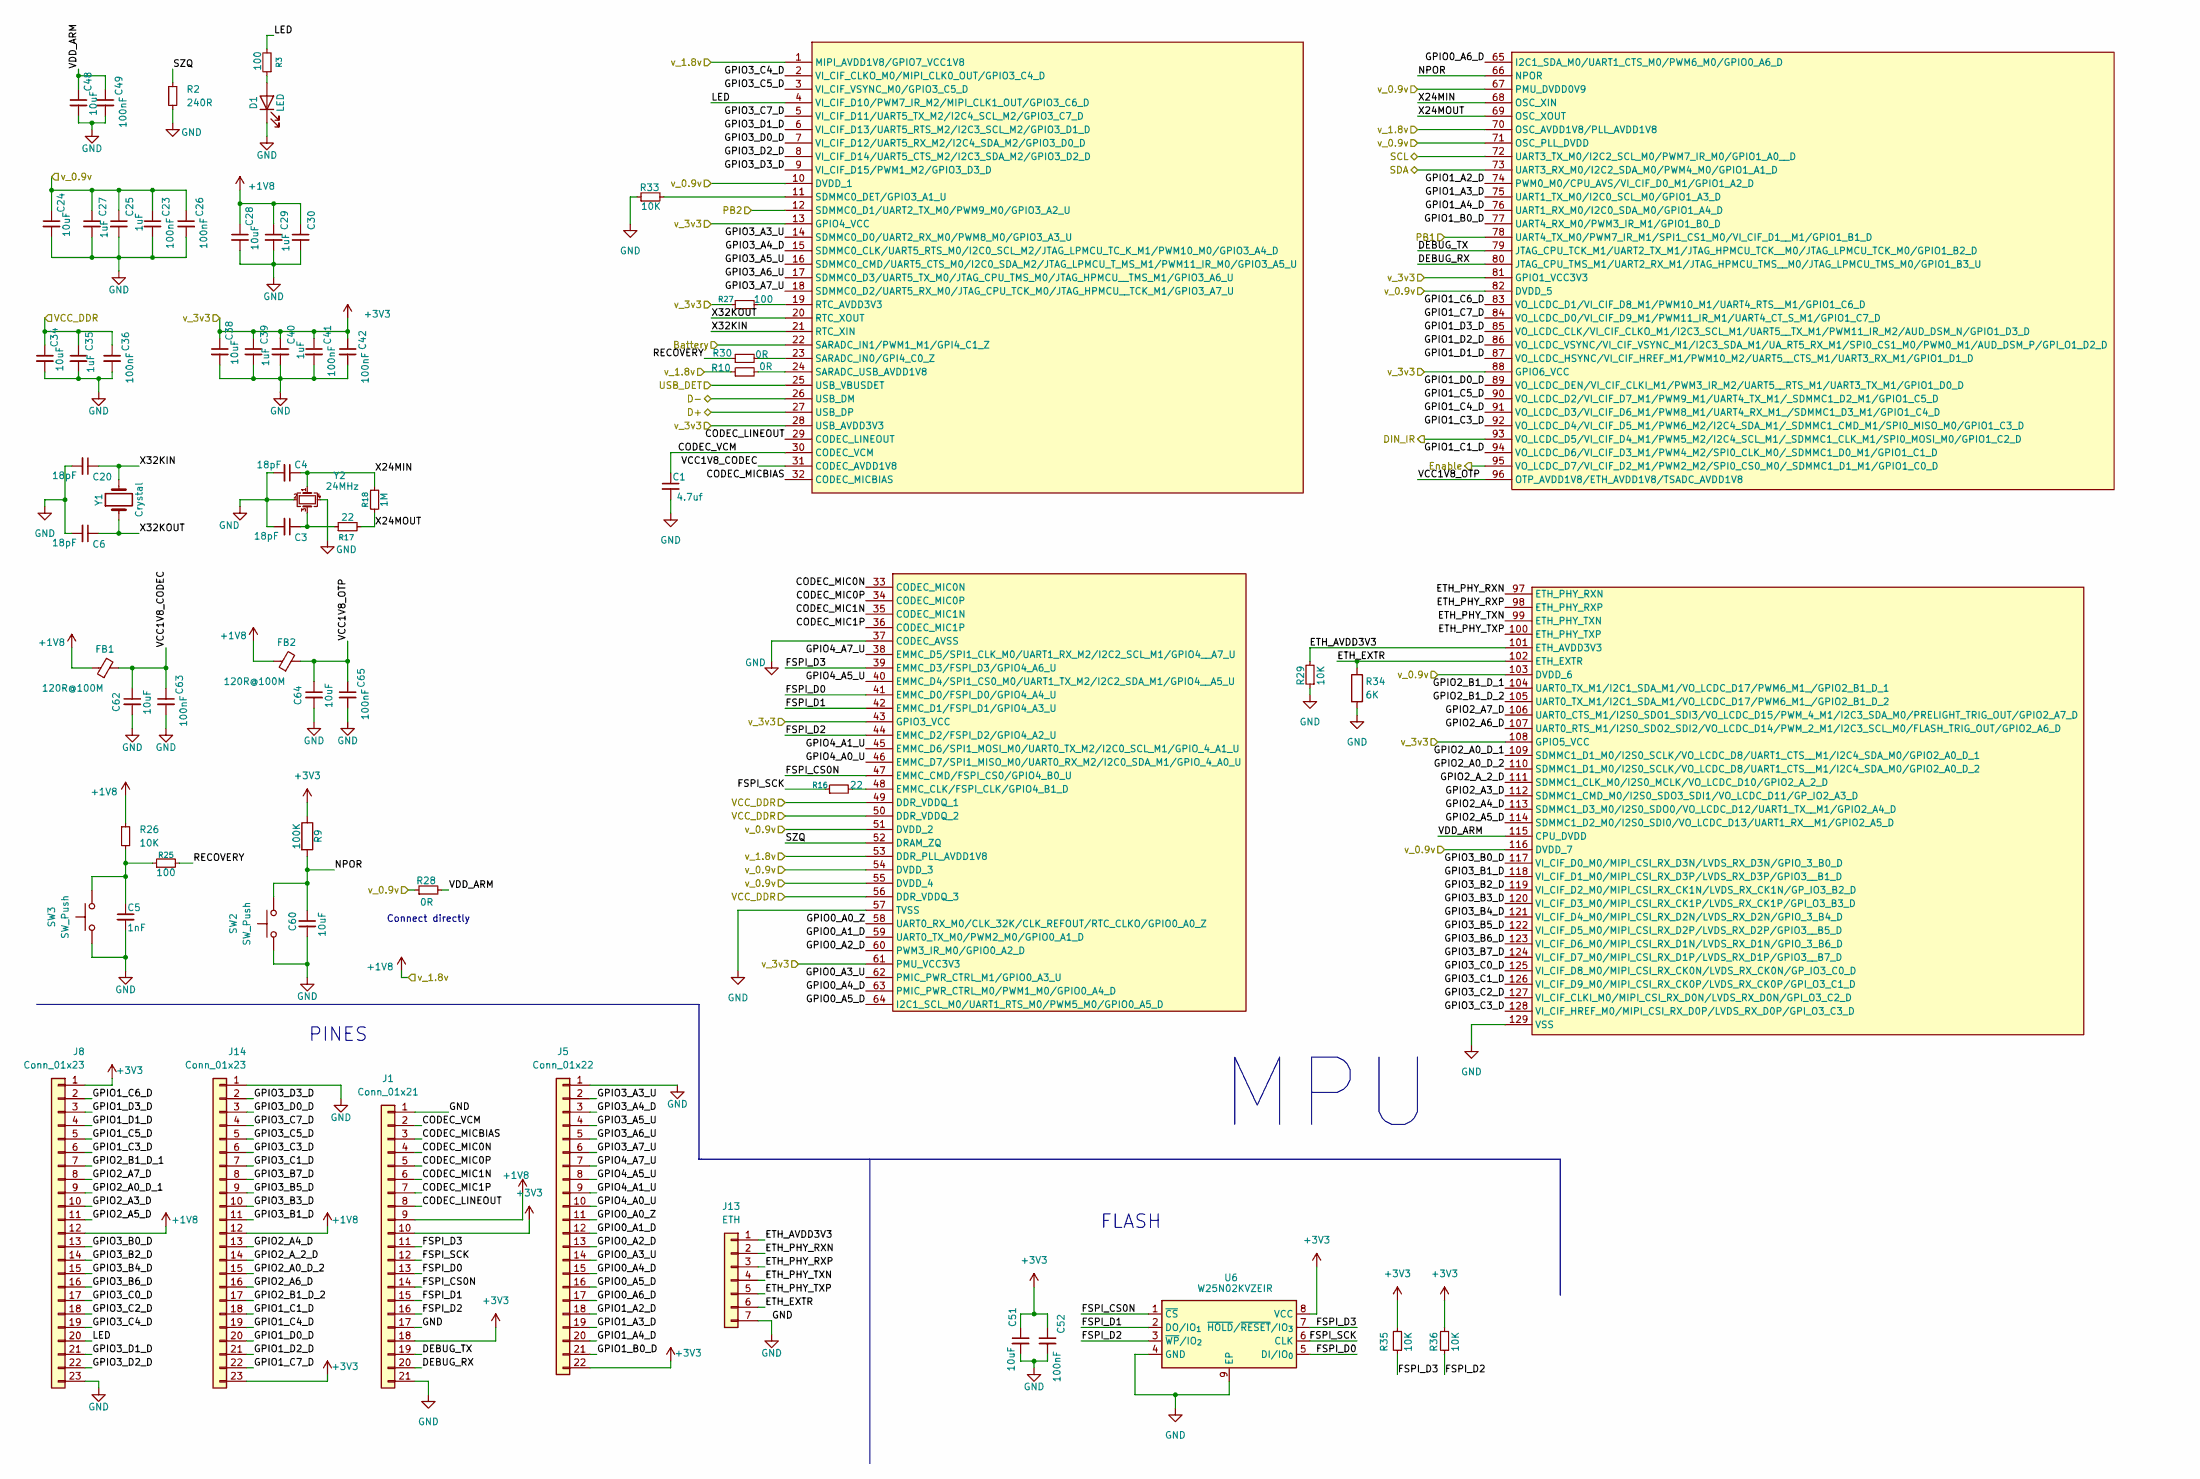
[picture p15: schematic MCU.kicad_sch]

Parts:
C1: 4.7uf; C_0402_1005Metric; LCSC# C6119795
C3, C4, C6, C20: 18pF; C_0402_1005Metric; LCSC# C161534
C5: 1nF; C_0402_1005Metric; LCSC# C189467
C23, C26, C36, C41, C42, C49, C52, C63, C65: 100nF; C_0402_1005Metric; LCSC# C77020
C24, C28, C34, C38, C48, C51, C62, C64: 10uF; C_0402_1005Metric; LCSC# C7472949
C25, C27, C29, C30, C35, C39, C40: 1uF; C_0402_1005Metric; LCSC# C52923
C60: 10uF; C_0603_1608Metric; LCSC# C96446
D1: LED; LED_0603_1608Metric; LCSC# C375573
FB1, FB2: 120R@100M; L_0603_1608Metric; LCSC# C14709
J1: Conn_01x21; PinHeader_1x21_P2.54mm_Vertical
J5: Conn_01x22; PinHeader_1x22_P2.54mm_Vertical
J8, J14: Conn_01x23; PinHeader_1x23_P2.54mm_Vertical
J13: ETH; PinHeader_1x07_P2.54mm_Vertical
R2: 240R; R_0402_1005Metric; LCSC# C25094
R3, R25, R27: 100; R_0402_1005Metric; LCSC# C2906860
R9: 100K; R_0402_1005Metric; LCSC# C844674
R10, R28, R30: 0R; R_0402_1005Metric; LCSC# C106231
R16, R17: 22; R_0402_1005Metric; LCSC# C159964
R18: 1M; R_0402_1005Metric; LCSC# C131492
R26, R29, R33, R35, R36: 10K; R_0402_1005Metric; LCSC# C2759535
R34: 6K; R_0805_2012Metric; LCSC# C2828725
SW2, SW3: SW_Push; SW_SPST_TL3342; LCSC# C318889
U6: W25N02KVZEIR; WSON-8-1EP_8x6mm_P1.27mm_EP3.4x4.3mm; LCSC# C3010298
U8: RV1106G3; LCSC# C5328706
Y1: Crystal; Crystal_SMD_3215-2Pin_3.2x1.5mm; LCSC# C620155
Y2: 24MHz; Crystal_SMD_3225-4Pin_3.2x2.5mm; LCSC# C70590

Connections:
+1V8: C28.1, C29.1, C30.1, FB1.1, FB2.1, J1.9, J8.12, J14.12, R10.1, R26.1, U8.1 (MIPI_AVDD1V8/GPIO7_VCC1V8), U8.53 (DDR_PLL_AVDD1V8), U8.70 (OSC_AVDD1V8/PLL_AVDD1V8); also elsewhere on the board
+3V3: C38.1, C39.1, C40.1, C41.1, C42.1, C51.1, C52.1, J1.10, J1.18, J5.22, J8.1, J14.23, R9.1, R27.1, R35.2, R36.2, U6.8 (VCC), U8.13 (GPIO4_VCC), U8.28 (USB_AVDD3V3), U8.43 (GPIO3_VCC), U8.61 (PMU_VCC3V3), U8.81 (GPIO1_VCC3V3), U8.88 (GPIO6_VCC), U8.108 (GPIO5_VCC); also elsewhere on the board
/Buck_Converter/VCC_DDR: C34.1, C35.1, C36.1, U8.49 (DDR_VDDQ_1), U8.50 (DDR_VDDQ_2), U8.56 (DDR_VDDQ_3); also elsewhere on the board
/Buck_Converter/v_0.9v: C23.1, C24.1, C25.1, C26.1, C27.1, R28.1, U8.10 (DVDD_1), U8.51 (DVDD_2), U8.54 (DVDD_3), U8.55 (DVDD_4), U8.67 (PMU_DVDD0V9), U8.71 (OSC_PLL_DVDD), U8.82 (DVDD_5), U8.103 (DVDD_6), U8.116 (DVDD_7); also elsewhere on the board
/MCU/Battery: U8.22 (SARADC_IN1/PWM1_M1/GPI4_C1_Z); also elsewhere on the board
/MCU/CODEC_LINEOUT: J1.8, U8.29 (CODEC_LINEOUT)
/MCU/CODEC_MIC0N: J1.4, U8.33 (CODEC_MIC0N)
/MCU/CODEC_MIC0P: J1.5, U8.34 (CODEC_MIC0P)
/MCU/CODEC_MIC1N: J1.6, U8.35 (CODEC_MIC1N)
/MCU/CODEC_MIC1P: J1.7, U8.36 (CODEC_MIC1P)
/MCU/CODEC_MICBIAS: J1.3, U8.32 (CODEC_MICBIAS)
/MCU/CODEC_VCM: C1.1, J1.2, U8.30 (CODEC_VCM)
/MCU/D+: U8.27 (USB_DP); also elsewhere on the board
/MCU/D-: U8.26 (USB_DM); also elsewhere on the board
/MCU/DEBUG_RX: J1.20, U8.80 (JTAG_CPU_TMS_M1/UART2_RX_M1/JTAG_HPMCU_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)
/MCU/DEBUG_TX: J1.19, U8.79 (JTAG_CPU_TCK_M1/UART2_TX_M1/JTAG_HPMCU_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)
/MCU/DIN_IR: U8.93 (VO_LCDC_D5/VI_CIF_D4_M1/PWM5_M2/I2C4_SC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); also elsewhere on the board
/MCU/ETH_AVDD3V3: J13.1, R29.2, U8.101 (ETH_AVDD3V3)
/MCU/ETH_EXTR: J13.6, R34.1, U8.102 (ETH_EXTR)
/MCU/ETH_PHY_RXN: J13.2, U8.97 (ETH_PHY_RXN)
/MCU/ETH_PHY_RXP: J13.3, U8.98 (ETH_PHY_RXP)
/MCU/ETH_PHY_TXN: J13.4, U8.99 (ETH_PHY_TXN)
/MCU/ETH_PHY_TXP: J13.5, U8.100 (ETH_PHY_TXP)
/MCU/Enable: U8.95 (VO_LCDC_D7/VI_CIF_D2_M1/PWM2_M2/SPI0_CS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); also elsewhere on the board
/MCU/FSPI_CS0N: J1.14, U6.1 (~CS), U8.47 (EMMC_CMD/FSPI_CS0/GPIO4_B0_U)
/MCU/FSPI_D0: J1.13, U6.5 (DI/IO_{0}), U8.41 (EMMC_D0/FSPI_D0/GPIO4_A4_U)
/MCU/FSPI_D1: J1.15, U6.2 (DO/IO_{1}), U8.42 (EMMC_D1/FSPI_D1/GPIO4_A3_U)
/MCU/FSPI_D2: J1.16, R36.1, U6.3 (~WP/IO_{2}), U8.44 (EMMC_D2/FSPI_D2/GPIO4_A2_U)
/MCU/FSPI_D3: J1.11, R35.1, U6.7 (~HOLD/~RESET/IO_{3}), U8.39 (EMMC_D3/FSPI_D3/GPIO4_A6_U)
/MCU/FSPI_SCK: J1.12, R16.1, U6.6 (CLK)
/MCU/GPIO0_A0_Z: J5.11, U8.58 (UART0_RX_M0/CLK_32K/CLK_REFOUT/RTC_CLKO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)
/MCU/GPIO0_A1_D: J5.12, U8.59 (UART0_TX_M0/PWM2_M0/GPIO0_A1_D)
/MCU/GPIO0_A2_D: J5.13, U8.60 (PWM3_IR_M0/GPIO0_A2_D)
/MCU/GPIO0_A3_U: J5.14, U8.62 (PMIC_PWR_CTRL_M1/GPIO0_A3_U)
/MCU/GPIO0_A4_D: J5.15, U8.63 (PMIC_PWR_CTRL_M0/PWM1_M0/GPIO0_A4_D)
/MCU/GPIO0_A5_D: J5.16, U8.64 (I2C1_SCL_M0/UART1_RTS_M0/PWM5_M0/GPIO0_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)
/MCU/GPIO0_A6_D: J5.17, U8.65 (I2C1_SDA_M0/UART1_CTS_M0/PWM6_M0/GPIO0_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)
/MCU/GPIO1_A2_D: J5.18, U8.74 (PWM0_M0/CPU_AVS/VI_CIF_D0_M1/GPIO1_A2_D)
/MCU/GPIO1_A3_D: J5.19, U8.75 (UART1_TX_M0/I2C0_SCL_M0/GPIO1_A3_D)
/MCU/GPIO1_A4_D: J5.20, U8.76 (UART1_RX_M0/I2C0_SDA_M0/GPIO1_A4_D)
/MCU/GPIO1_B0_D: J5.21, U8.77 (UART4_RX_M0/PWM3_IR_M1/GPIO1_B0_D)
/MCU/GPIO1_C1_D: J14.18, U8.94 (VO_LCDC_D6/VI_CIF_D3_M1/PWM4_M2/SPI0_CL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)
/MCU/GPIO1_C3_D: J8.6, U8.92 (VO_LCDC_D4/VI_CIF_D5_M1/PWM6_M2/I2C4_SD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)
/MCU/GPIO1_C4_D: J14.19, U8.91 (VO_LCDC_D3/VI_CIF_D6_M1/PWM8_M1/UART4_R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)
/MCU/GPIO1_C5_D: J8.5, U8.90 (VO_LCDC_D2/VI_CIF_D7_M1/PWM9_M1/UART4_T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)
/MCU/GPIO1_C6_D: J8.2, U8.83 (VO_LCDC_D1/VI_CIF_D8_M1/PWM10_M1/UART4_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)
/MCU/GPIO1_C7_D: J14.22, U8.84 (VO_LCDC_D0/VI_CIF_D9_M1/PWM11_IR_M1/UAR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)
/MCU/GPIO1_D0_D: J14.20, U8.89 (VO_LCDC_DEN/VI_CIF_CLKI_M1/PWM3_IR_M2/U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)
/MCU/GPIO1_D1_D: J8.4, U8.87 (VO_LCDC_HSYNC/VI_CIF_HREF_M1/PWM10_M2/U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)
/MCU/GPIO1_D2_D: J14.21, U8.86 (VO_LCDC_VSYNC/VI_CIF_VSYNC_M1/I2C3_SDA_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)
/MCU/GPIO1_D3_D: J8.3, U8.85 (VO_LCDC_CLK/VI_CIF_CLKO_M1/I2C3_SCL_M1/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)
/MCU/GPIO2_A0_D_1: J8.9, U8.109 (SDMMC1_D1_M0/I2S0_SCLK/VO_LCDC_D8/UART1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)
/MCU/GPIO2_A0_D_2: J14.15, U8.110 (SDMMC1_D1_M0/I2S0_SCLK/VO_LCDC_D8/UART1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)
/MCU/GPIO2_A3_D: J8.10, U8.112 (SDMMC1_CMD_M0/I2S0_SDO3_SDI1/VO_LCDC_D1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)
/MCU/GPIO2_A4_D: J14.13, U8.113 (SDMMC1_D3_M0/I2S0_SDO0/VO_LCDC_D12/UART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)
/MCU/GPIO2_A5_D: J8.11, U8.114 (SDMMC1_D2_M0/I2S0_SDI0/VO_LCDC_D13/UART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)
/MCU/GPIO2_A6_D: J14.16, U8.107 (UART0_RTS_M1/I2S0_SDO2_SDI2/VO_LCDC_D14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)
/MCU/GPIO2_A7_D: J8.8, U8.106 (UART0_CTS_M1/I2S0_SDO1_SDI3/VO_LCDC_D15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)
/MCU/GPIO2_A_2_D: J14.14, U8.111 (SDMMC1_CLK_M0/I2S0_MCLK/VO_LCDC_D10/GPI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)
/MCU/GPIO2_B1_D_1: J8.7, U8.104 (UART0_TX_M1/I2C1_SDA_M1/VO_LCDC_D17/PWM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)
/MCU/GPIO2_B1_D_2: J14.17, U8.105 (UART0_TX_M1/I2C1_SDA_M1/VO_LCDC_D17/PWM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)
/MCU/GPIO3_A3_U: J5.2, U8.14 (SDMMC0_D0/UART2_RX_M0/PWM8_M0/GPIO3_A3_U)
/MCU/GPIO3_A4_D: J5.3, U8.15 (SDMMC0_CLK/UART5_RTS_M0/I2C0_SCL_M2/JTA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)
/MCU/GPIO3_A5_U: J5.4, U8.16 (SDMMC0_CMD/UART5_CTS_M0/I2C0_SDA_M2/JTA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)
/MCU/GPIO3_A6_U: J5.5, U8.17 (SDMMC0_D3/UART5_TX_M0/JTAG_CPU_TMS_M0/J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)
/MCU/GPIO3_A7_U: J5.6, U8.18 (SDMMC0_D2/UART5_RX_M0/JTAG_CPU_TCK_M0/J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)
/MCU/GPIO3_B0_D: J8.13, U8.117 (VI_CIF_D0_M0/MIPI_CSI_RX_D3N/LVDS_RX_D3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)
/MCU/GPIO3_B1_D: J14.11, U8.118 (VI_CIF_D1_M0/MIPI_CSI_RX_D3P/LVDS_RX_D3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)
/MCU/GPIO3_B2_D: J8.14, U8.119 (VI_CIF_D2_M0/MIPI_CSI_RX_CK1N/LVDS_RX_C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)
/MCU/GPIO3_B3_D: J14.10, U8.120 (VI_CIF_D3_M0/MIPI_CSI_RX_CK1P/LVDS_RX_C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)
/MCU/GPIO3_B4_D: J8.15, U8.121 (VI_CIF_D4_M0/MIPI_CSI_RX_D2N/LVDS_RX_D2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)
/MCU/GPIO3_B5_D: J14.9, U8.122 (VI_CIF_D5_M0/MIPI_CSI_RX_D2P/LVDS_RX_D2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)
/MCU/GPIO3_B6_D: J8.16, U8.123 (VI_CIF_D6_M0/MIPI_CSI_RX_D1N/LVDS_RX_D1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)
/MCU/GPIO3_B7_D: J14.8, U8.124 (VI_CIF_D7_M0/MIPI_CSI_RX_D1P/LVDS_RX_D1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)
/MCU/GPIO3_C0_D: J8.17, U8.125 (VI_CIF_D8_M0/MIPI_CSI_RX_CK0N/LVDS_RX_C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)
/MCU/GPIO3_C1_D: J14.7, U8.126 (VI_CIF_D9_M0/MIPI_CSI_RX_CK0P/LVDS_RX_C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)
/MCU/GPIO3_C2_D: J8.18, U8.127 (VI_CIF_CLKI_M0/MIPI_CSI_RX_D0N/LVDS_RX_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)
/MCU/GPIO3_C3_D: J14.6, U8.128 (VI_CIF_HREF_M0/MIPI_CSI_RX_D0P/LVDS_RX_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)
/MCU/GPIO3_C4_D: J8.19, U8.2 (VI_CIF_CLKO_M0/MIPI_CLK0_OUT/GPIO3_C4_D)
/MCU/GPIO3_C5_D: J14.5, U8.3 (VI_CIF_VSYNC_M0/GPIO3_C5_D)
/MCU/GPIO3_C7_D: J14.4, U8.5 (VI_CIF_D11/UART5_TX_M2/I2C4_SCL_M2/GPIO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)
/MCU/GPIO3_D0_D: J14.3, U8.7 (VI_CIF_D12/UART5_RX_M2/I2C4_SDA_M2/GPIO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)
/MCU/GPIO3_D1_D: J8.21, U8.6 (VI_CIF_D13/UART5_RTS_M2/I2C3_SCL_M2/GPI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)
/MCU/GPIO3_D2_D: J8.22, U8.8 (VI_CIF_D14/UART5_CTS_M2/I2C3_SDA_M2/GPI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)
/MCU/GPIO3_D3_D: J14.2, U8.9 (VI_CIF_D15/PWM1_M2/GPIO3_D3_D)
/MCU/GPIO4_A0_U: J5.10, U8.46 (EMMC_D7/SPI1_MISO_M0/UART0_RX_M2/I2C0_S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)
/MCU/GPIO4_A1_U: J5.9, U8.45 (EMMC_D6/SPI1_MOSI_M0/UART0_TX_M2/I2C0_S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)
/MCU/GPIO4_A5_U: J5.8, U8.40 (EMMC_D4/SPI1_CS0_M0/UART1_TX_M2/I2C2_SD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)
/MCU/GPIO4_A7_U: J5.7, U8.38 (EMMC_D5/SPI1_CLK_M0/UART1_RX_M2/I2C2_SC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)
/MCU/LED: J8.20, R3.2, U8.4 (VI_CIF_D10/PWM7_IR_M2/MIPI_CLK1_OUT/GPI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)
/MCU/NPOR: C60.1, R9.2, SW2.2, U8.66 (NPOR)
/MCU/PB1: U8.78 (UART4_TX_M0/PWM7_IR_M1/SPI1_CS1_M0/VI_C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); also elsewhere on the board
/MCU/PB2: U8.12 (SDMMC0_D1/UART2_TX_M0/PWM9_M0/GPIO3_A2_U); also elsewhere on the board
/MCU/RECOVERY: R25.2, R30.1
/MCU/SCL: U8.72 (UART3_TX_M0/I2C2_SCL_M0/PWM7_IR_M0/GPIO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); also elsewhere on the board
/MCU/SDA: U8.73 (UART3_RX_M0/I2C2_SDA_M0/PWM4_M0/GPIO1_A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); also elsewhere on the board
/MCU/SZQ: R2.1, U8.52 (DRAM_ZQ)
/MCU/USB_DET: U8.25 (USB_VBUSDET); also elsewhere on the board
/MCU/VCC1V8_CODEC: C62.1, C63.1, FB1.2, U8.31 (CODEC_AVDD1V8)
/MCU/VCC1V8_OTP: C64.1, C65.1, FB2.2, U8.96 (OTP_AVDD1V8/ETH_AVDD1V8/TSADC_AVDD1V8)
/MCU/VDD_ARM: C48.1, C49.1, R28.2, U8.115 (CPU_DVDD)
/MCU/X24MIN: C4.1, R18.1, U8.68 (OSC_XIN), Y2.1
/MCU/X24MOUT: R17.2, R18.2, U8.69 (OSC_XOUT)
/MCU/X32KIN: C20.1, U8.21 (RTC_XIN), Y1.2
/MCU/X32KOUT: C6.1, U8.20 (RTC_XOUT), Y1.1
GND: C1.2, C3.2, C4.2, C5.2, C6.2, C20.2, C23.2, C24.2, C25.2, C26.2, C27.2, C28.2, C29.2, C30.2, C34.2, C35.2, C36.2, C38.2, C39.2, C40.2, C41.2, C42.2, C48.2, C49.2, C51.2, C52.2, C60.2, C62.2, C63.2, C64.2, C65.2, D1.1 (K), J1.1, J1.17, J1.21, J5.1, J8.23, J13.7, J14.1, R2.2, R29.1, R33.1, R34.2, SW2.1, SW3.1, U6.4 (GND), U6.9 (EP), U8.37 (CODEC_AVSS), U8.57 (TVSS), U8.129 (VSS), Y2.2, Y2.4; also elsewhere on the board
unnamed: C3.1, R17.1, Y2.3
unnamed: C5.1, R25.1, R26.2, SW3.2
unnamed: D1.2 (A), R3.1
unnamed: R27.2, U8.19 (RTC_AVDD3V3)
unnamed: R30.2, U8.23 (SARADC_IN0/GPI4_C0_Z)
unnamed: R10.2, U8.24 (SARADC_USB_AVDD1V8)
unnamed: R33.2, U8.11 (SDMMC0_DET/GPIO3_A1_U)
unnamed: R16.2, U8.48 (EMMC_CLK/FSPI_CLK/GPIO4_B1_D)

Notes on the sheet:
MPU
Connect directly
PINES
FLASH

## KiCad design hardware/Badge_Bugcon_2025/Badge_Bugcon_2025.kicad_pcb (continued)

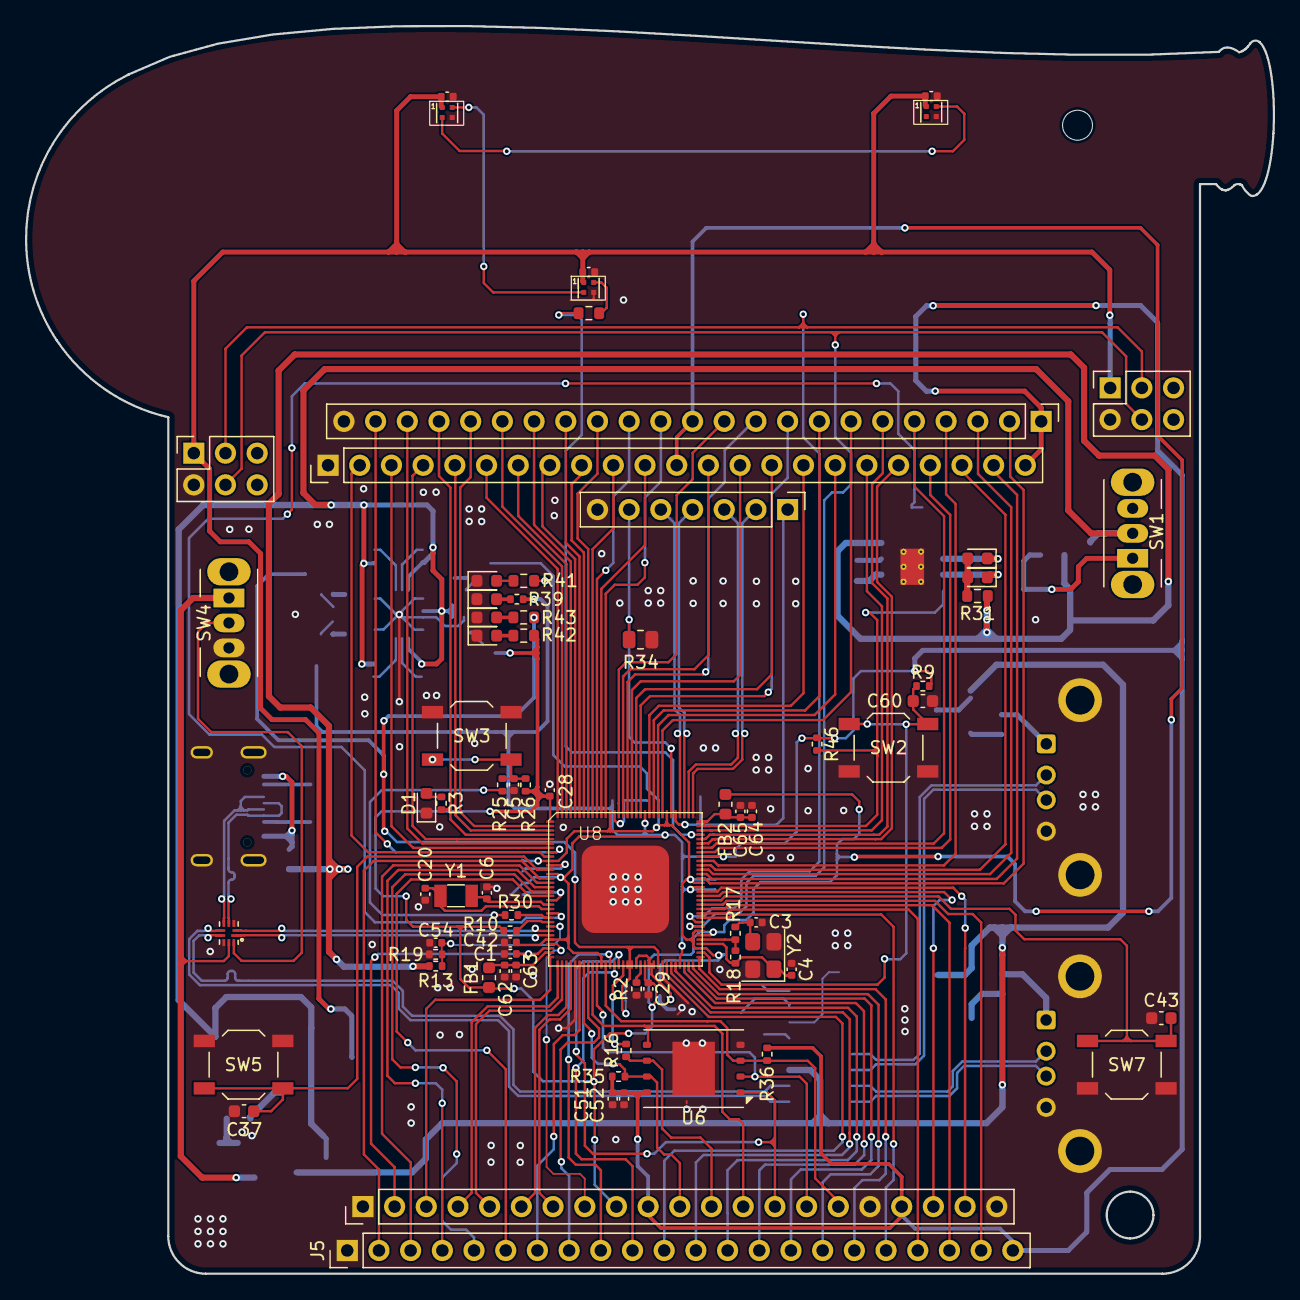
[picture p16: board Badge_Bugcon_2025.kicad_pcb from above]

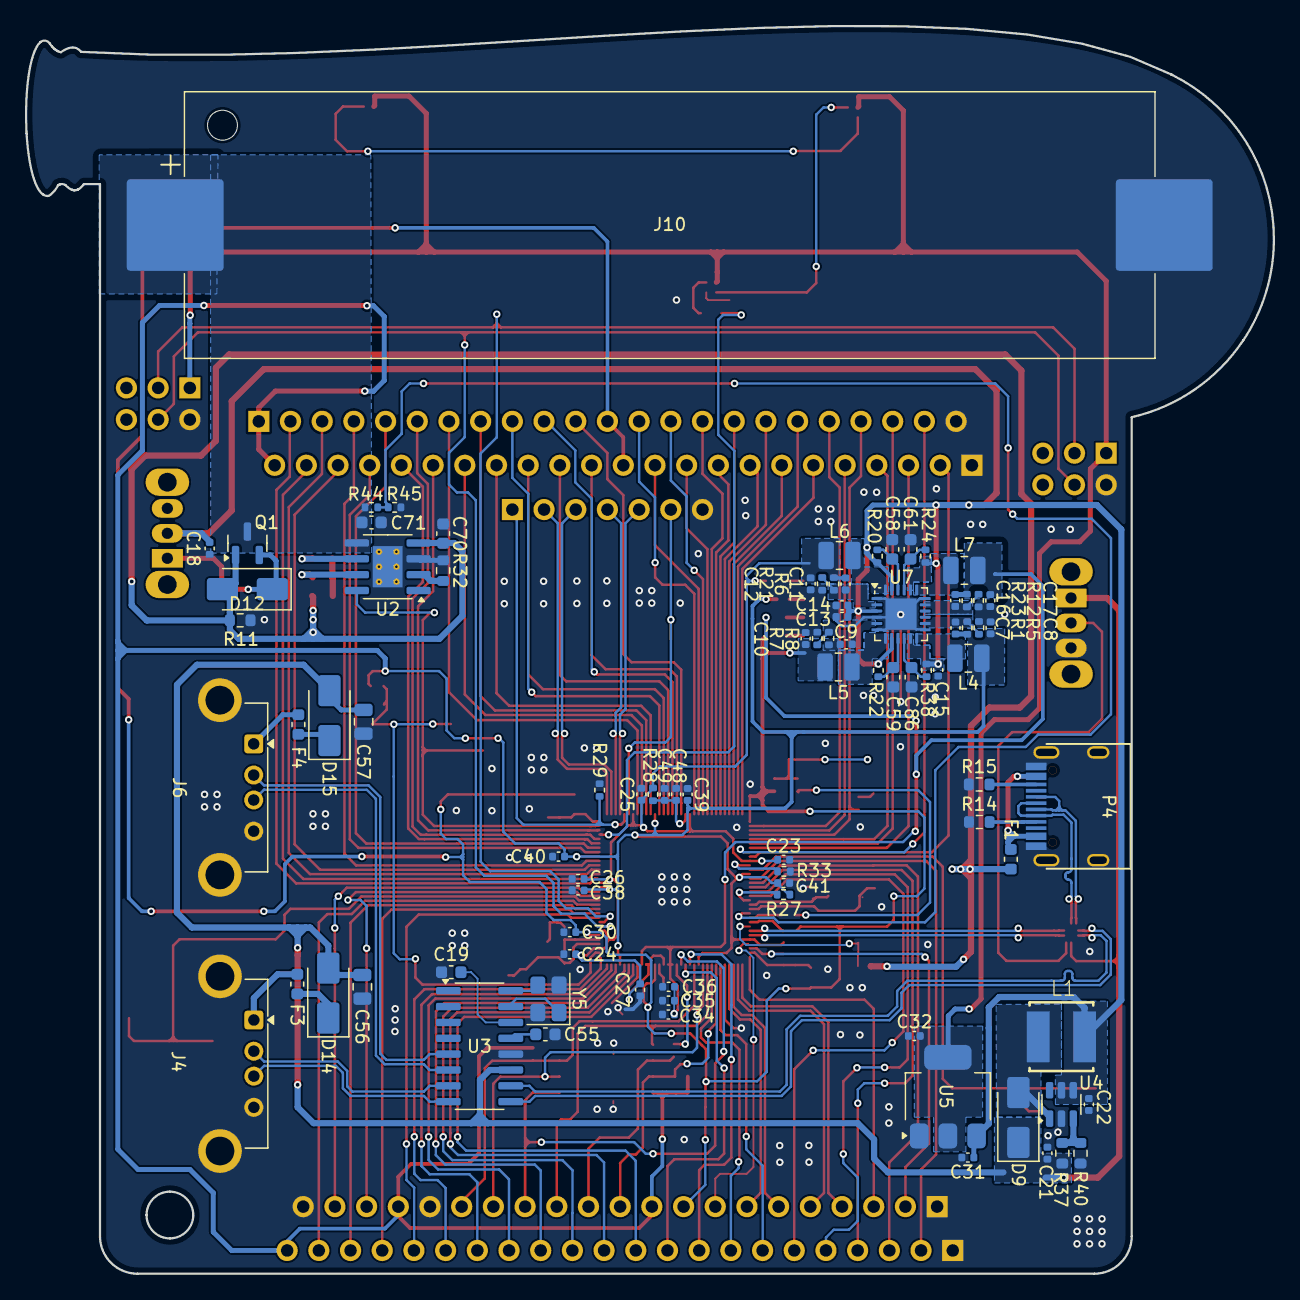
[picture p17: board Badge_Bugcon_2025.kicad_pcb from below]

Board: 2 copper layers, 100.0 x 100.0 mm, 162 parts (88 on the bottom side), 165 nets.

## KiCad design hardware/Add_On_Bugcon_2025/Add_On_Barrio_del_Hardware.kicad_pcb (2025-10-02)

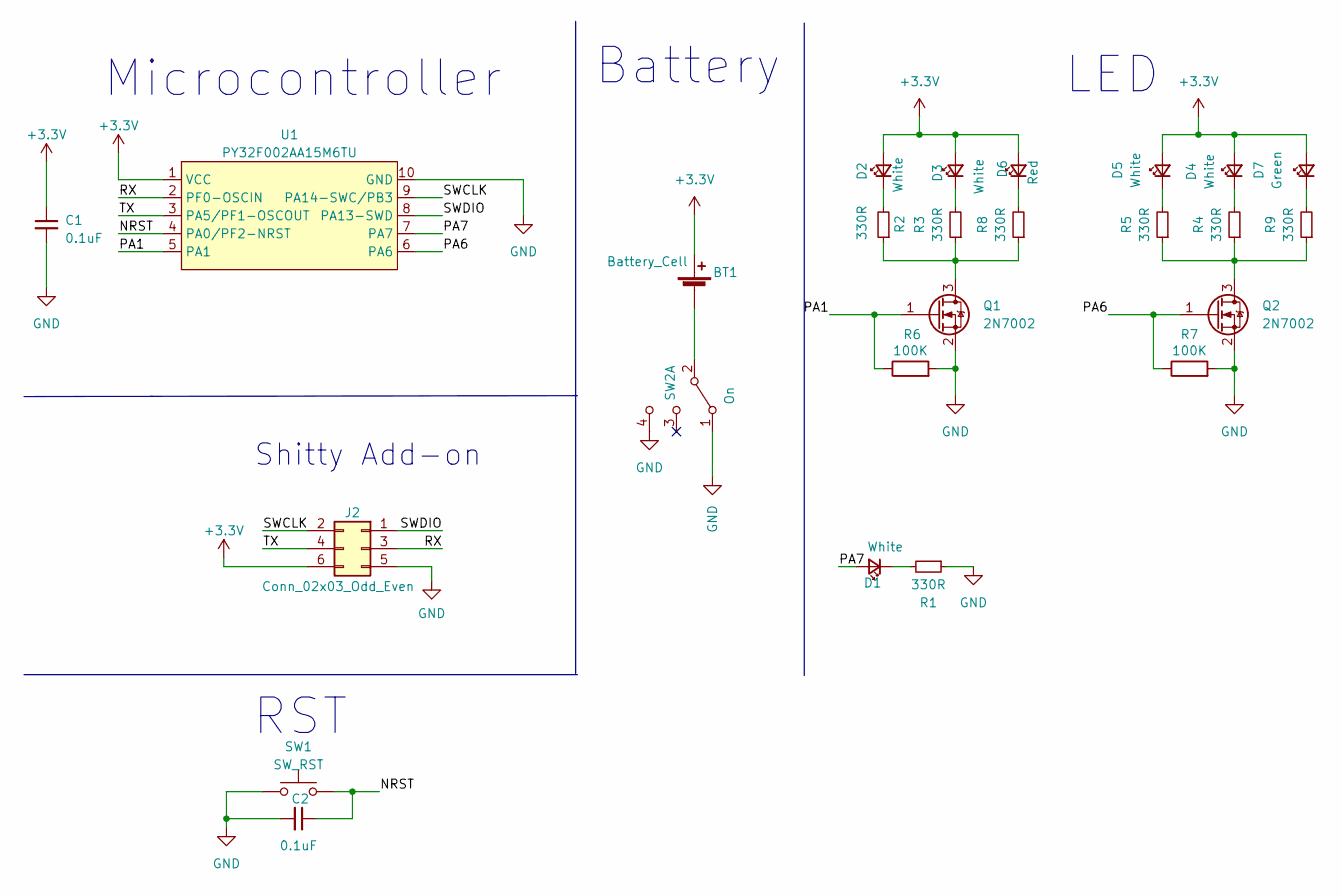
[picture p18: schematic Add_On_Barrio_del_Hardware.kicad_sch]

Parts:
BT1: Battery_Cell; BAT-HLD-001; LCSC# C964833
C1, C2: 0.1uF; C_0805_2012Metric; LCSC# C282732
D1: White; LED_0603_1608Metric; LCSC# C2290
D2, D3, D4, D5: White; LYT77K-K2M1-NoHole
D6: Red; LED_0603_1608Metric; LCSC# C2286
D7: Green; LED_0603_1608Metric; LCSC# C916074
J2: Conn_02x03_Odd_Even; PinHeader_2x03_P2.54mm_Vertical_SMD; LCSC# C780054
Q1, Q2: 2N7002; SOT-23; LCSC# C8545
R1, R2, R3, R4, R5, R8, R9: 330R; R_0603_1608Metric; LCSC# C105881
R6, R7: 100K; R_0805_2012Metric; LCSC# C96346
SW1: SW_RST; SW_SPST_TL3342; LCSC# C318889
SW2: On; MSK12C02; LCSC# C431540
U1: PY32F002AA15M6TU; PY32F002AA15M; LCSC# C5292058

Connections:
+3.3V: BT1.2 (+), C1.1, D2.2 (A), D3.2 (A), D4.2 (A), D5.2 (A), D6.2 (A), D7.2 (A), J2.6, U1.1 (VCC)
/NRST: C2.1, SW1.2, U1.4 (PA0/PF2-NRST)
/PA1: Q1.1 (G), R6.1, U1.5 (PA1)
/PA6: Q2.1 (G), R7.1, U1.6 (PA6)
/PA7: D1.2 (A), U1.7 (PA7)
/RX: J2.3, U1.2 (PF0-OSCIN)
/SWCLK: J2.2, U1.9 (PA14-SWC/PB3)
/SWDIO: J2.1, U1.8 (PA13-SWD)
/TX: J2.4, U1.3 (PA5/PF1-OSCOUT)
GND: C1.2, C2.2, J2.5, Q1.2 (S), Q2.2 (S), R1.1, R6.2, R7.2, SW1.1, SW2.1 (A), SW2.4 (C), U1.10 (GND)
unnamed: BT1.1 (-), SW2.2 (B)
unnamed: D1.1 (K), R1.2
unnamed: D2.1 (K), R2.2
unnamed: D3.1 (K), R3.2
unnamed: D4.1 (K), R4.2
unnamed: D5.1 (K), R5.2
unnamed: D6.1 (K), R8.2
unnamed: D7.1 (K), R9.2
unnamed: Q1.3 (D), R2.1, R3.1, R8.1
unnamed: Q2.3 (D), R4.1, R5.1, R9.1

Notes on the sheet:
LED
Shitty Add-on
RST
Microcontroller
Battery

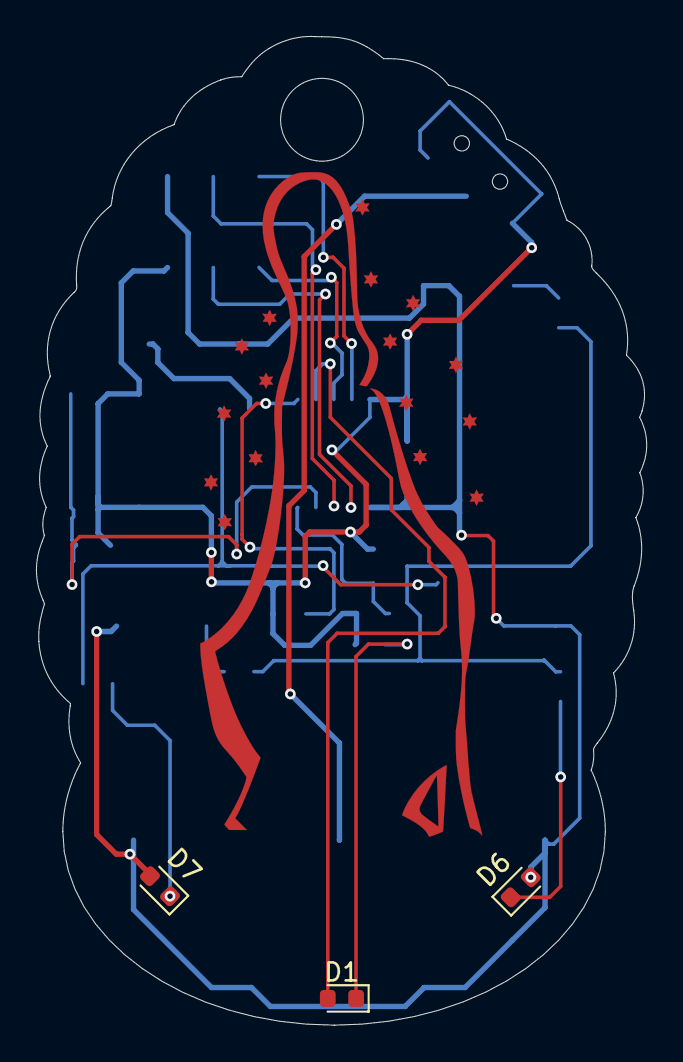
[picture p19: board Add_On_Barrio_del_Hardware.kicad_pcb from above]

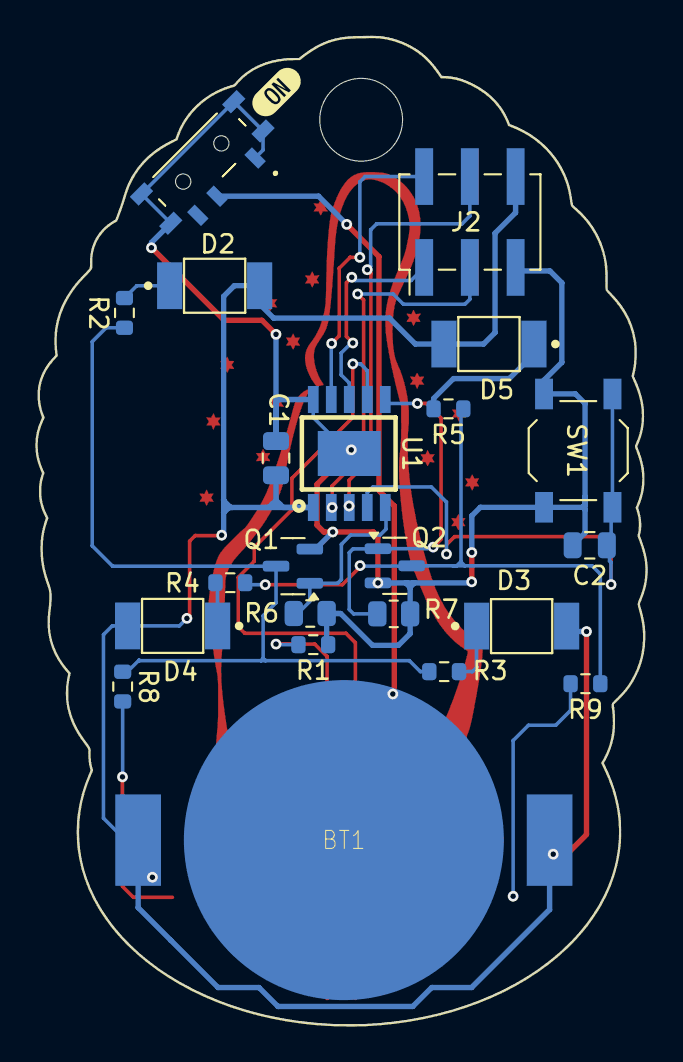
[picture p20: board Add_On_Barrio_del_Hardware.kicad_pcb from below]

Board: 2 copper layers, 33.9 x 54.9 mm, 27 parts (23 on the bottom side), 20 nets.

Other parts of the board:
Ref**: Val**; VIRGEN DE GUADALUPE
kibuzzard-68DB0924: G***; kibuzzard-68DB0924

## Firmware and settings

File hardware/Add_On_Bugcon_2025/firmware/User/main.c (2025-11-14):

/**
 ******************************************************************************
 * @file    main.c
 * @author  MCU Application Team
 * @brief   Main program body
 ******************************************************************************
 * @attention
 *
 * <h2><center>&copy; Copyright (c) Puya Semiconductor Co.
 * All rights reserved.</center></h2>
 *
 * <h2><center>&copy; Copyright (c) 2016 STMicroelectronics.
 * All rights reserved.</center></h2>
 *
 * This software component is licensed by ST under BSD 3-Clause license,
 * the "License"; You may not use this file except in compliance with the
 * License. You may obtain a copy of the License at:
 *                        opensource.org/licenses/BSD-3-Clause
 *
 * J-Link Connections: https://private-user-images.githubusercontent.com/44976441/277049150-2c44cddc-163c-4924-840f-2b99760bbca3.png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
 * PUYA instructions: https://github.com/ElectronicCats/puya-projects
 *
 ******************************************************************************
 */

/* Includes ------------------------------------------------------------------*/
#include "py32f0xx_bsp_printf.h"
#include <stdint.h>

/* Private define ------------------------------------------------------------*/
/* Private variables ---------------------------------------------------------*/
/* Private user code ---------------------------------------------------------*/
/* Private macro -------------------------------------------------------------*/
/* Private function prototypes -----------------------------------------------*/
static void APP_LedConfig(void);
uint16_t delay1 = 2000, delay3 = 4000;
uint8_t delay = 200, delay2 = 250, delay4 = 50;


// Sequence 1
void eyesSequence()
{
  HAL_GPIO_OnPin(GPIOA, GPIO_PIN_7);
  HAL_Delay(delay1);
  HAL_GPIO_OffPin(GPIOA, GPIO_PIN_7);
  HAL_Delay(delay);

  //Bink
  HAL_GPIO_OnPin(GPIOA, GPIO_PIN_1);
  HAL_GPIO_OnPin(GPIOA, GPIO_PIN_6);
  HAL_Delay(delay);
  HAL_GPIO_OffPin(GPIOA, GPIO_PIN_1);
  HAL_GPIO_OffPin(GPIOA, GPIO_PIN_6);
  HAL_Delay(delay);
  HAL_GPIO_OnPin(GPIOA, GPIO_PIN_1);
  HAL_GPIO_OnPin(GPIOA, GPIO_PIN_6);
  HAL_Delay(delay);
  HAL_GPIO_OffPin(GPIOA, GPIO_PIN_1);
  HAL_GPIO_OffPin(GPIOA, GPIO_PIN_6);
  HAL_Delay(delay);
  HAL_GPIO_OnPin(GPIOA, GPIO_PIN_1);
  HAL_GPIO_OnPin(GPIOA, GPIO_PIN_6);
  HAL_Delay(delay);
  HAL_GPIO_OffPin(GPIOA, GPIO_PIN_1);
  HAL_GPIO_OffPin(GPIOA, GPIO_PIN_6);
  HAL_Delay(delay);
  HAL_GPIO_OnPin(GPIOA, GPIO_PIN_1);
  HAL_GPIO_OnPin(GPIOA, GPIO_PIN_6);
  HAL_Delay(delay);
  HAL_GPIO_OffPin(GPIOA, GPIO_PIN_1);
  HAL_GPIO_OffPin(GPIOA, GPIO_PIN_6);
  HAL_Delay(delay);
}

// Sequence 2
void wingSequence()
{
  HAL_GPIO_OnPin(GPIOA, GPIO_PIN_6);
  HAL_Delay(delay);
  HAL_GPIO_OffPin(GPIOA, GPIO_PIN_6);
  HAL_Delay(delay);
  HAL_GPIO_OnPin(GPIOA, GPIO_PIN_1);
  HAL_Delay(delay);
  HAL_GPIO_OffPin(GPIOA, GPIO_PIN_1);
  HAL_Delay(delay);
  HAL_GPIO_OnPin(GPIOA, GPIO_PIN_6);
  HAL_Delay(delay);
  HAL_GPIO_OffPin(GPIOA, GPIO_PIN_6);
  HAL_Delay(delay);
  HAL_GPIO_OnPin(GPIOA, GPIO_PIN_1);
  HAL_Delay(delay);
  HAL_GPIO_OffPin(GPIOA, GPIO_PIN_1);
  HAL_Delay(delay);
  HAL_GPIO_OnPin(GPIOA, GPIO_PIN_6);
  HAL_Delay(delay);
  HAL_GPIO_OffPin(GPIOA, GPIO_PIN_6);
  HAL_Delay(delay);
  HAL_GPIO_OnPin(GPIOA, GPIO_PIN_1);
  HAL_Delay(delay);
  HAL_GPIO_OffPin(GPIOA, GPIO_PIN_1);
  HAL_Delay(delay);
  HAL_GPIO_OnPin(GPIOA, GPIO_PIN_6);
  HAL_Delay(delay);
  HAL_GPIO_OffPin(GPIOA, GPIO_PIN_6);
  HAL_Delay(delay);
  HAL_GPIO_OnPin(GPIOA, GPIO_PIN_1);
  HAL_Delay(delay);
  HAL_GPIO_OffPin(GPIOA, GPIO_PIN_1);
  HAL_Delay(delay);
}

//Sequence 3
void flat()
{
  HAL_GPIO_OnPin(GPIOA, GPIO_PIN_6);
  HAL_Delay(delay1);
  HAL_GPIO_OnPin(GPIOA, GPIO_PIN_7);
  HAL_Delay(delay1);
  HAL_GPIO_OnPin(GPIOA, GPIO_PIN_1);
  HAL_Delay(delay3);
}

// Sequence 4
void rouletteSequence()
{
  HAL_GPIO_OnPin(GPIOA, GPIO_PIN_6);
  HAL_Delay(delay2);
  HAL_GPIO_OnPin(GPIOA, GPIO_PIN_7); 
  HAL_Delay(delay2);
  HAL_GPIO_OnPin(GPIOA, GPIO_PIN_1); 
  HAL_Delay(delay2);

  HAL_GPIO_OnPin(GPIOA, GPIO_PIN_6);
  HAL_Delay(delay2);
  HAL_GPIO_OnPin(GPIOA, GPIO_PIN_7); 
  HAL_Delay(delay2);
  HAL_GPIO_OnPin(GPIOA, GPIO_PIN_1); 
  HAL_Delay(delay2);
}

// Sequence 5
void allSequence()
{
  HAL_GPIO_OnPin(GPIOA, GPIO_PIN_6); 
  HAL_GPIO_OnPin(GPIOA, GPIO_PIN_7); 
  HAL_GPIO_OnPin(GPIOA, GPIO_PIN_1); 
  HAL_Delay(delay1);
  HAL_GPIO_OffPin(GPIOA, GPIO_PIN_6); 
  HAL_GPIO_OffPin(GPIOA, GPIO_PIN_7); 
  HAL_GPIO_OffPin(GPIOA, GPIO_PIN_1); 
  HAL_Delay(delay);

  //Blink
  HAL_GPIO_OnPin(GPIOA, GPIO_PIN_6); 
  HAL_GPIO_OnPin(GPIOA, GPIO_PIN_7); 
  HAL_GPIO_OnPin(GPIOA, GPIO_PIN_1); 
  HAL_Delay(delay1);
  HAL_GPIO_OffPin(GPIOA, GPIO_PIN_6); 
  HAL_GPIO_OffPin(GPIOA, GPIO_PIN_7); 
  HAL_GPIO_OffPin(GPIOA, GPIO_PIN_1); 
  HAL_Delay(delay);
  HAL_GPIO_OnPin(GPIOA, GPIO_PIN_6); 
  HAL_GPIO_OnPin(GPIOA, GPIO_PIN_7); 
  HAL_GPIO_OnPin(GPIOA, GPIO_PIN_1); 
  HAL_Delay(delay1);
  HAL_GPIO_OffPin(GPIOA, GPIO_PIN_6); 
  HAL_GPIO_OffPin(GPIOA, GPIO_PIN_7); 
  HAL_GPIO_OffPin(GPIOA, GPIO_PIN_1); 
  HAL_Delay(delay);
  HAL_GPIO_OnPin(GPIOA, GPIO_PIN_6); 
  HAL_GPIO_OnPin(GPIOA, GPIO_PIN_7); 
  HAL_GPIO_OnPin(GPIOA, GPIO_PIN_1); 
  HAL_Delay(delay1);
  HAL_GPIO_OffPin(GPIOA, GPIO_PIN_6); 
  HAL_GPIO_OffPin(GPIOA, GPIO_PIN_7); 
  HAL_GPIO_OffPin(GPIOA, GPIO_PIN_1); 
  HAL_Delay(delay);
}

// Seqeuence 6
void slowrouletteSequence()
{
  HAL_GPIO_OnPin(GPIOA, GPIO_PIN_6); 
  HAL_Delay(delay2);
  HAL_GPIO_OffPin(GPIOA, GPIO_PIN_6); 
  HAL_Delay(delay2);
  HAL_GPIO_OnPin(GPIOA, GPIO_PIN_7); 
  HAL_Delay(delay2);
  HAL_GPIO_OffPin(GPIOA, GPIO_PIN_7); 
  HAL_Delay(delay2);
  HAL_GPIO_OnPin(GPIOA, GPIO_PIN_1); 
  HAL_Delay(delay2);
  HAL_GPIO_OffPin(GPIOA, GPIO_PIN_1); 
  HAL_Delay(delay2);

  HAL_GPIO_OnPin(GPIOA, GPIO_PIN_6); 
  HAL_Delay(delay2);
  HAL_GPIO_OffPin(GPIOA, GPIO_PIN_6); 
  HAL_Delay(delay2);
  HAL_GPIO_OnPin(GPIOA, GPIO_PIN_7); 
  HAL_Delay(delay2);
  HAL_GPIO_OffPin(GPIOA, GPIO_PIN_7); 
  HAL_Delay(delay2);
  HAL_GPIO_OnPin(GPIOA, GPIO_PIN_1); 
  HAL_Delay(delay2);
  HAL_GPIO_OffPin(GPIOA, GPIO_PIN_1); 
  HAL_Delay(delay2);
}

// Sequence 7
void fastrouletteSequence()
{
  HAL_GPIO_OnPin(GPIOA, GPIO_PIN_6);
  HAL_Delay(delay4);
  HAL_GPIO_OffPin(GPIOA, GPIO_PIN_6);
  HAL_Delay(delay4);
  HAL_GPIO_OnPin(GPIOA, GPIO_PIN_7); 
  HAL_Delay(delay4);
  HAL_GPIO_OffPin(GPIOA, GPIO_PIN_7);
  HAL_Delay(delay4);
  HAL_GPIO_OnPin(GPIOA, GPIO_PIN_1); 
  HAL_Delay(delay4);
  HAL_GPIO_OffPin(GPIOA, GPIO_PIN_1);
  HAL_Delay(delay4);

  HAL_GPIO_OnPin(GPIOA, GPIO_PIN_6);
  HAL_Delay(delay4);
  HAL_GPIO_OffPin(GPIOA, GPIO_PIN_6);
  HAL_Delay(delay4);
  HAL_GPIO_OnPin(GPIOA, GPIO_PIN_7); 
  HAL_Delay(delay4);
  HAL_GPIO_OffPin(GPIOA, GPIO_PIN_7);
  HAL_Delay(delay4);
  HAL_GPIO_OnPin(GPIOA, GPIO_PIN_1); 
  HAL_Delay(delay4);
  HAL_GPIO_OffPin(GPIOA, GPIO_PIN_1);
  HAL_Delay(delay4);

  HAL_GPIO_OnPin(GPIOA, GPIO_PIN_6);
  HAL_Delay(delay4);
  HAL_GPIO_OffPin(GPIOA, GPIO_PIN_6);
  HAL_Delay(delay4);
  HAL_GPIO_OnPin(GPIOA, GPIO_PIN_7); 
  HAL_Delay(delay4);
  HAL_GPIO_OffPin(GPIOA, GPIO_PIN_7);
  HAL_Delay(delay4);
  HAL_GPIO_OnPin(GPIOA, GPIO_PIN_1); 
  HAL_Delay(delay4);
  HAL_GPIO_OffPin(GPIOA, GPIO_PIN_1);
  HAL_Delay(delay4);

  HAL_GPIO_OnPin(GPIOA, GPIO_PIN_6);
  HAL_Delay(delay4);
  HAL_GPIO_OffPin(GPIOA, GPIO_PIN_6);
  HAL_Delay(delay4);
  HAL_GPIO_OnPin(GPIOA, GPIO_PIN_7); 
  HAL_Delay(delay4);
  HAL_GPIO_OffPin(GPIOA, GPIO_PIN_7);
  HAL_Delay(delay4);
  HAL_GPIO_OnPin(GPIOA, GPIO_PIN_1); 
  HAL_Delay(delay4);
  HAL_GPIO_OffPin(GPIOA, GPIO_PIN_1);
  HAL_Delay(delay4);

  HAL_GPIO_OnPin(GPIOA, GPIO_PIN_6);
  HAL_Delay(delay4);
  HAL_GPIO_OffPin(GPIOA, GPIO_PIN_6);
  HAL_Delay(delay4);
  HAL_GPIO_OnPin(GPIOA, GPIO_PIN_7); 
  HAL_Delay(delay4);
  HAL_GPIO_OffPin(GPIOA, GPIO_PIN_7);
  HAL_Delay(delay4);
  HAL_GPIO_OnPin(GPIOA, GPIO_PIN_1); 
  HAL_Delay(delay4);
  HAL_GPIO_OffPin(GPIOA, GPIO_PIN_1);
  HAL_Delay(delay4);

  HAL_GPIO_OnPin(GPIOA, GPIO_PIN_6);
  HAL_Delay(delay4);
  HAL_GPIO_OffPin(GPIOA, GPIO_PIN_6);
  HAL_Delay(delay4);
  HAL_GPIO_OnPin(GPIOA, GPIO_PIN_7); 
  HAL_Delay(delay4);
  HAL_GPIO_OffPin(GPIOA, GPIO_PIN_7);
  HAL_Delay(delay4);
  HAL_GPIO_OnPin(GPIOA, GPIO_PIN_1); 
  HAL_Delay(delay4);
  HAL_GPIO_OffPin(GPIOA, GPIO_PIN_1);
  HAL_Delay(delay4);

  HAL_GPIO_OnPin(GPIOA, GPIO_PIN_6);
  HAL_Delay(delay4);
  HAL_GPIO_OffPin(GPIOA, GPIO_PIN_6);
  HAL_Delay(delay4);
  HAL_GPIO_OnPin(GPIOA, GPIO_PIN_7); 
  HAL_Delay(delay4);
  HAL_GPIO_OffPin(GPIOA, GPIO_PIN_7);
  HAL_Delay(delay4);
  HAL_GPIO_OnPin(GPIOA, GPIO_PIN_1); 
  HAL_Delay(delay4);
  HAL_GPIO_OffPin(GPIOA, GPIO_PIN_1);
  HAL_Delay(delay4);

  HAL_GPIO_OnPin(GPIOA, GPIO_PIN_6);
  HAL_Delay(delay4);
  HAL_GPIO_OffPin(GPIOA, GPIO_PIN_6);
  HAL_Delay(delay4);
  HAL_GPIO_OnPin(GPIOA, GPIO_PIN_7); 
  HAL_Delay(delay4);
  HAL_GPIO_OffPin(GPIOA, GPIO_PIN_7);
  HAL_Delay(delay4);
  HAL_GPIO_OnPin(GPIOA, GPIO_PIN_1); 
  HAL_Delay(delay4);
  HAL_GPIO_OffPin(GPIOA, GPIO_PIN_1);
  HAL_Delay(delay4);
}

void sequences(int sequence)
{
  switch (sequence)
  {
  case 1:
    eyesSequence();
    break;
  case 2:
    wingSequence();
    break;
  case 3:
    flat();
    break;
  case 4:
    rouletteSequence();
    break;
  case 5:
    allSequence();
    break;
  case 6:
    slowrouletteSequence();
    break;
  case 7:
    fastrouletteSequence();
    break;
  default:
    HAL_Delay(1000);
    break;
  }
}

int main(void)
{
  HAL_Init();

  APP_LedConfig();

  BSP_USART_Config();
  
  while (1)
  {
    for (uint8_t c = 1; c < 8; c++)
    {
      sequences(c);
    }
  }
}

static void APP_LedConfig(void)
{
  GPIO_InitTypeDef GPIO_InitStruct;

  __HAL_RCC_GPIOA_CLK_ENABLE();

  GPIO_InitStruct.Pin = GPIO_PIN_1;
  GPIO_InitStruct.Mode = GPIO_MODE_OUTPUT_PP;
  GPIO_InitStruct.Pull = GPIO_PULLUP;
  GPIO_InitStruct.Speed = GPIO_SPEED_FREQ_HIGH;
  HAL_GPIO_Init(GPIOA, &GPIO_InitStruct);

  __HAL_RCC_GPIOA_CLK_ENABLE();

  GPIO_InitStruct.Pin = GPIO_PIN_6;
  GPIO_InitStruct.Mode = GPIO_MODE_OUTPUT_PP;
  GPIO_InitStruct.Pull = GPIO_PULLUP;
  GPIO_InitStruct.Speed = GPIO_SPEED_FREQ_HIGH;
  HAL_GPIO_Init(GPIOA, &GPIO_InitStruct);

  __HAL_RCC_GPIOA_CLK_ENABLE();

  GPIO_InitStruct.Pin = GPIO_PIN_7;
  GPIO_InitStruct.Mode = GPIO_MODE_OUTPUT_PP;
  GPIO_InitStruct.Pull = GPIO_PULLUP;
  GPIO_InitStruct.Speed = GPIO_SPEED_FREQ_HIGH;

  HAL_GPIO_Init(GPIOA, &GPIO_InitStruct);

  __HAL_RCC_GPIOA_CLK_ENABLE();

  GPIO_InitStruct.Pin = GPIO_PIN_5;
  GPIO_InitStruct.Mode = GPIO_MODE_OUTPUT_PP;
  GPIO_InitStruct.Pull = GPIO_PULLUP;
  GPIO_InitStruct.Speed = GPIO_SPEED_FREQ_HIGH;

  HAL_GPIO_Init(GPIOA, &GPIO_InitStruct);

  __HAL_RCC_GPIOF_CLK_ENABLE();

  GPIO_InitStruct.Pin = GPIO_PIN_0;
  GPIO_InitStruct.Mode = GPIO_MODE_OUTPUT_PP;
  GPIO_InitStruct.Pull = GPIO_PULLUP;
  GPIO_InitStruct.Speed = GPIO_SPEED_FREQ_HIGH;

  HAL_GPIO_Init(GPIOF, &GPIO_InitStruct);
}

void APP_ErrorHandler(void)
{
  while (1)
    ;
}

#ifdef USE_FULL_ASSERT

void assert_failed(uint8_t *file, uint32_t line)
{
  while (1)
  {
  }
}
#endif /* USE_FULL_ASSERT */

/************************ (C) COPYRIGHT Puya *****END OF FILE******************/

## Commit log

2025-09-30 feat(Hw)_Update PCB_Hole_Added
    [Add_On_Barrio_del_Hardware.kicad_pcb, Add_On_Barrio_del_Hardware.kicad_sch]
2025-10-21 feat(Hw): Add leds change crytsla routing
    [Badge_Bugcon_2025.kicad_pcb, Otros.kicad_sch]
2025-10-21 update connections same image layer
    [Badge_Bugcon_2025.kicad_pcb, USB.kicad_sch]
2025-10-22 fix(hw): route pads
    [Badge_Bugcon_2025.kicad_pcb, USB.kicad_sch]
2025-11-24 docs: Add access information to README
    Added access credentials for the device.
